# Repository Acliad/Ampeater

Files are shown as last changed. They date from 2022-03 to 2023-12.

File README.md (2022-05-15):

# Overview
This project is a 50 W electronic load. The table below outlines the basic specs for the load.

| Description | Spec |
|---|---|
| Supply Voltage | 12 V |
| Slew Rate | 10 A/µs |
| Maximum Current | 10 A |
| Maximum Power Dissipation | 50 W |
| Program Resolution (low range / high range) | 1 mA / 10 mA |
| Program Accuracy | 0.2% $\pm$ 0.2% FS |
| Maximum Overshoot | 1% |
| Measurement Readout Accuracy | 0.2% $\pm$ 0.2% FS |

The primary challenge with designing an electronic load is to making it stable over a wide range of load currents and input conditions. This challenges becomes worse when the design demands a fast rise time. The target slew rate for this load is 10 A/µs, which is quite fast. In comparison, the [Keysight EL34243A](https://www.keysight.com/zz/en/assets/3120-1430/data-sheets/EL30000-Series.pdf) has a slew rate of about 5 A/µs. 

This challenge is two-fold. The initial and obvious challenge is the control loop, which is discussed in detail in the [Theory Of Operation](#theory-of-operation) section. Simply, this requires proper compensation to maintain stability and rise time. The more nefarious issue is the issue of input impedance, largely due to the inductance of the wires connecting the load to the source being tested. This inductance is, in general, not known and can vary widely, in the range of 50 nH to 2 uH between short, heavy gauge wire and garden-variety banana cables. This inductance has a large affect on the control loop and can significantly change the rise time and stability of the load. 

Because the current level and slew rate are so large, the slew rate and overshoot specs are defined to be valid for input inductances in the range of 100 nH–roughly 10 cm of 12 AWG wire. This was the assumed input inductance during the design stage. 

# Design and Simulation
## The Control Loop
Figure 1 shows the main control circuit. The main compensation components have been highlighted. Q201 and gate resistors are used to switch the current range between 1 A and 10 A. For this analysis, assume either R211+R212 OR R214 is connected. R202 isolates the output of the opamp from the gate capacitance, which is required for stability. This compensator is known as a [*Type III compensator*](https://www.ti.com/seclit/ml/slup340/slup340.pdf). There are two compensators, each designed to sink up to 0.5/5.0 A. This is done to reduce power dissipation in each transistor.

<p align="center">
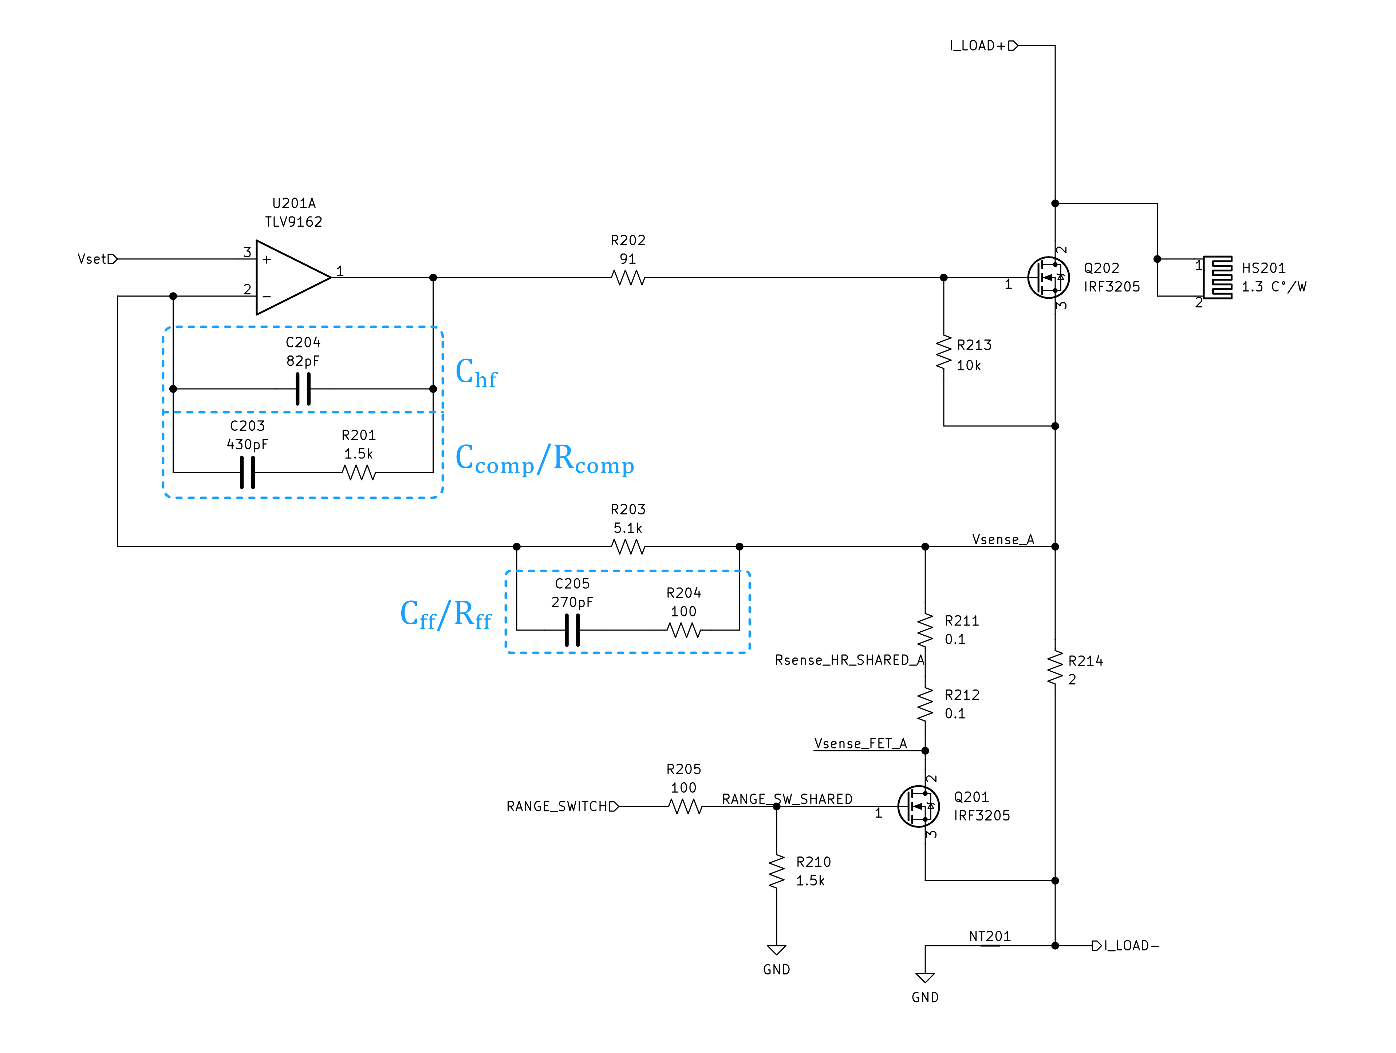
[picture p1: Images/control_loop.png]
 
<figcaption align = "center"><b>Figure 1: Control Loop Circuit</b></figcaption>
</p>

The poles and zeros of the compensator can be set by the compensation components outlined in Figure 1, with equations given in [Switch-mode power converter compensation made easy](https://www.ti.com/seclit/ml/slup340/slup340.pdf).

Figure 2 shows the SPICE simulation setup for the control loop, where the spice models for the TLV9162 were provided by TI and the spice models for the IRF3205 were provided by Infineon. R6 and C4 are used to compensate for the inductance L1. 

<p align="center">
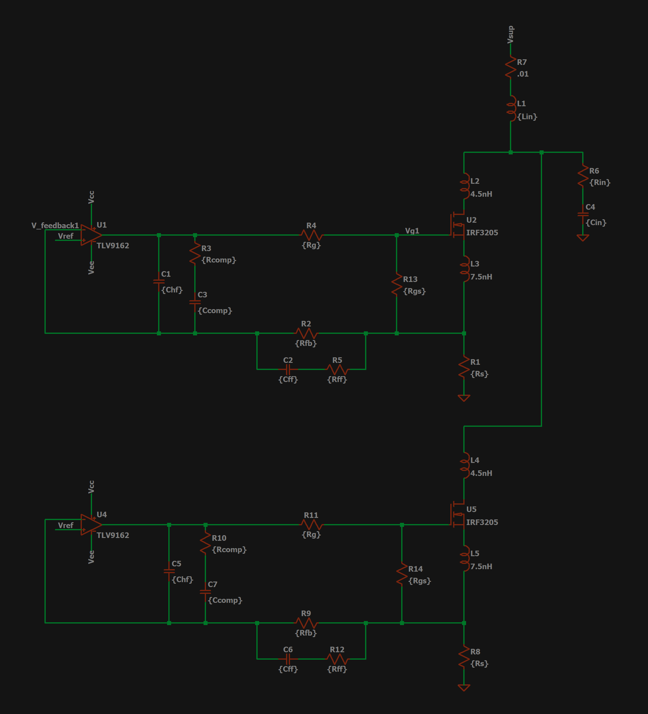
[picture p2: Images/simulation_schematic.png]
 
<figcaption align = "center"><b>Figure 2: Simulation Schematic</b></figcaption>
</p>

The values for the compensation components were tuned until the desired step response was obtained. Figure 3 below shows the simulated step response to 10 A for RS = 0.2, L1 = 100 nH. The compensation values are given in Figure 1. The overshoot spec is met and the 10% to 90% rise time was measured to be 1.03µs. 

<p align="center">
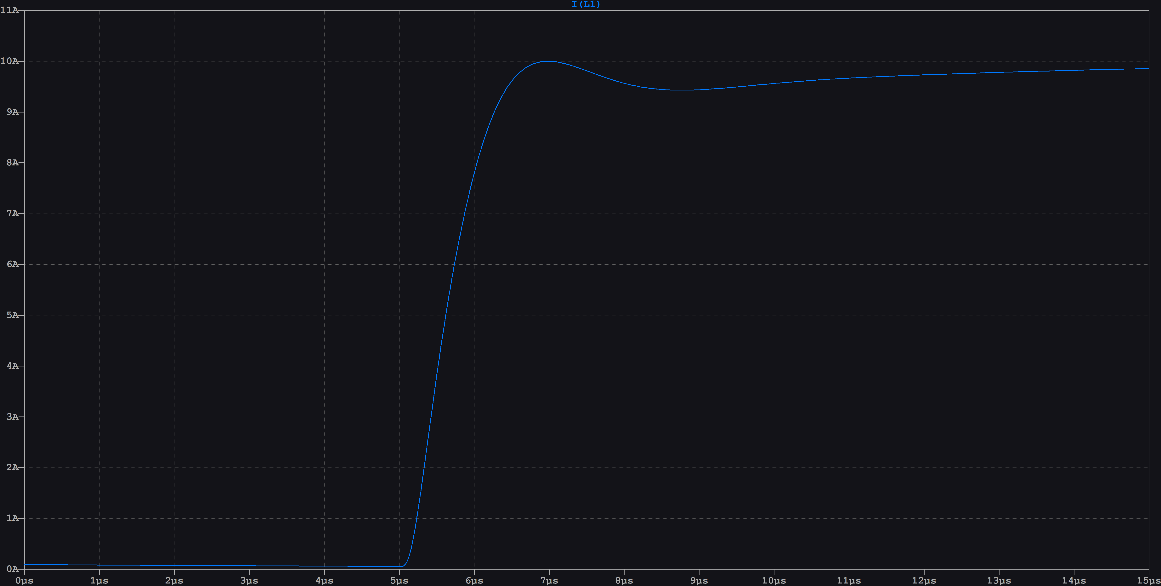
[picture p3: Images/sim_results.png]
 
<figcaption align = "center"><b>Figure 3: Simulated Step Response</b></figcaption>
</p>

## Controlling The Control Loop
An STM32L041 was used as the microcontroller for this board. It was chosen for its availability at the time of design (which was during the 2022 parts shortage). It features an on-board 12-bit ADC, which has enough resolution to meet the measurement specs, but the resolution can be further improved using hardware oversampling. 

A DAC is used to set the control voltage for the control loop. The chosen DAC is the ADI AD5452YRM, a fast settling time R2-R DAC. This DAC was chosen as the step response of the DAC needed to be at least as fast as the response of the overall control circuit. The chosen DAC should be more than sufficent for the task. 

Figure 4 shows the DAC arrangement. As noted in the image, the reference voltage is being fed into the current output pin of the DAC and the output voltage is being taken from the Vref pin. R2-R DACs generally allow this arrangement (unless the output is internally buffered), but typically require the reference voltage to be much less than than the supply voltage to overcome the required Vgs of the internal FETs. The ADI datasheet is not clear on how much larger Vcc should be, so the first attempt simply used a 3.3V supply. 

The output impedance of an R2-R DAC in this reverse arrangement is equal to the R value, which is 10k for the AD5452YRM. It is possible that the RC time constant could slow down the output transition, so the traces connecting the DAC to the opamp input should be kept short.
<p align="center">
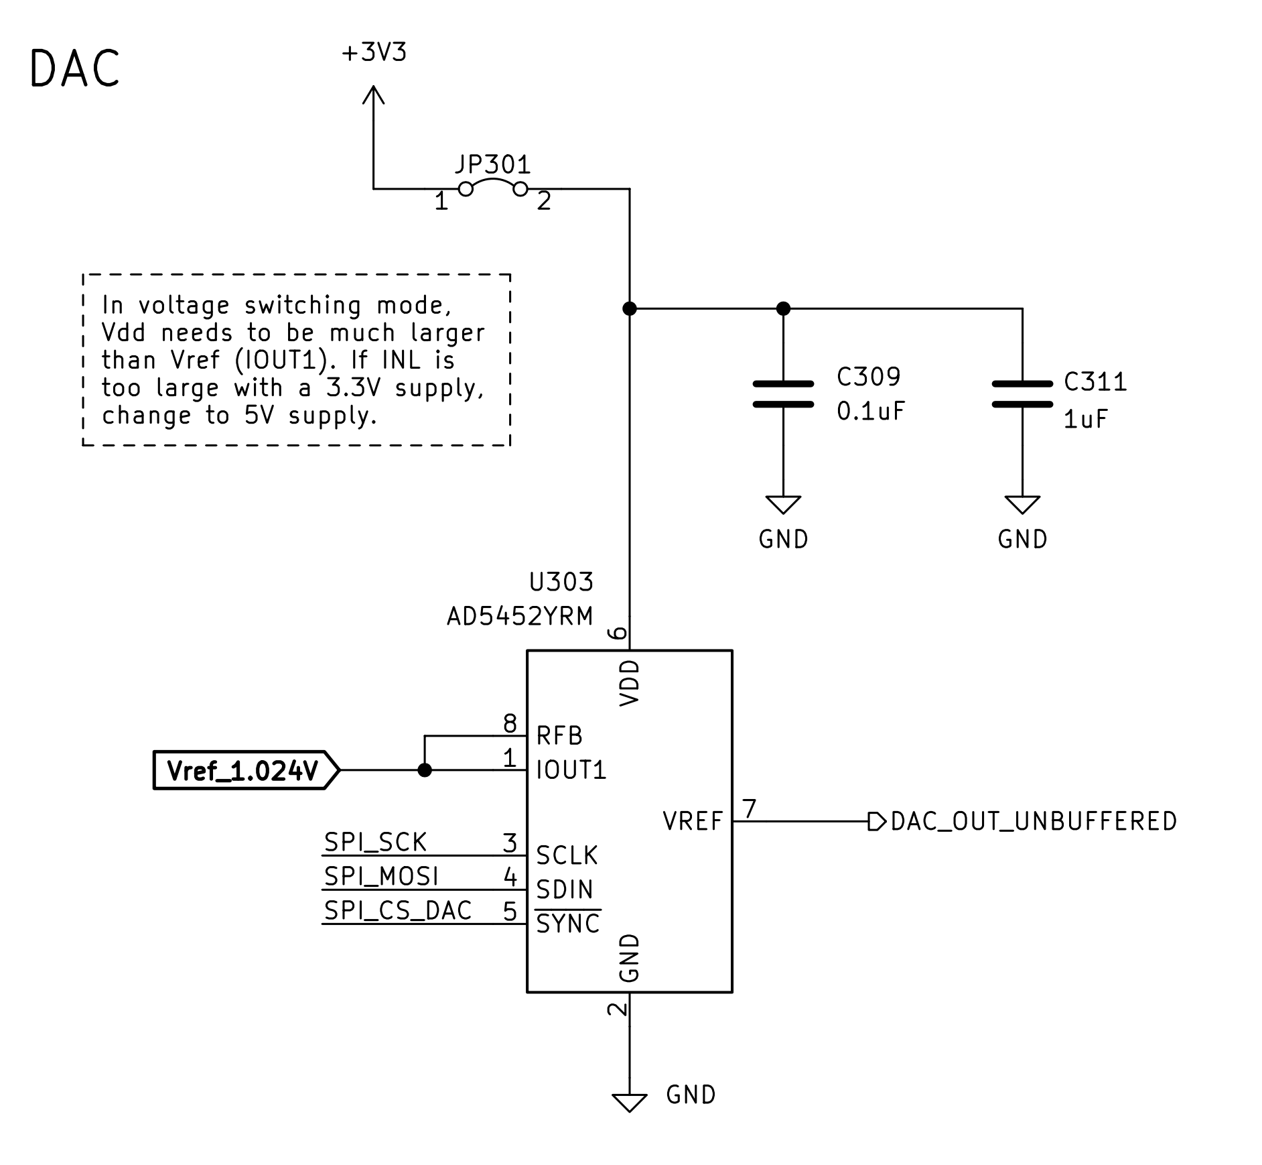
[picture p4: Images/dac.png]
 
<figcaption align = "center"><b>Figure 4: DAC Schematic Block</b></figcaption>
</p>

## Heatsinking
A large heatsink was chosen to be capable of dissipating at least 50 W with forced air cooling. The thermal calculations were done assuming smooth fin design, however, the chosen heatsink has serrated fins which should significantly improve the heatsinking ability. 

## Human Interfacing
A colored LCD, two pushbuttons, and a rotary encoder with a built-in push button is used to interface with the electronic load. The primary function of the buttons are:
- Output On/Off
- Slew Rate Setting
- Range Selection

The rotary encoder is used to set the load current.

# Results
The final board is shown in Figure 5. All basic DC functions worked including range switching, current measurement, and current sinking up to 10 A. It was found to be stable over the entire range of set current, with some small amount of ringing on the 10 A setting with 2X3ft (6ft ~ 2nH input inductance). 

<p align="center">
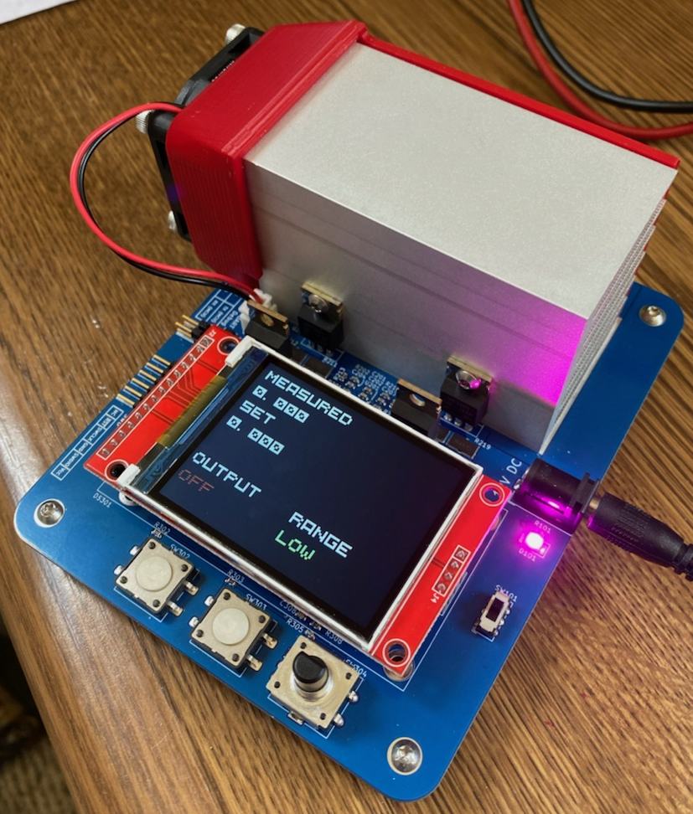
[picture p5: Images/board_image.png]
 
<figcaption align = "center"><b>Figure 5: Assembled Ampeater</b></figcaption>
</p>

The output was found to be overdamped when two 8 cm lengths of 12 AWG wire were used to connect to the load. The scope capture is shown in Figure 6. The capture is measured across Rsense of one of the control loops with a resistance of ~0.2 Ohms, so 1 V equals 10 A of load current. The capture shows a clearly overdamped response, which makes the load very stable but much slower than desired with a rise time of ~11 µs. To adjust this, the compensation components must be tuned and the measurement performed until the results are acceptable. This is still a TODO item. 

<p align="center">
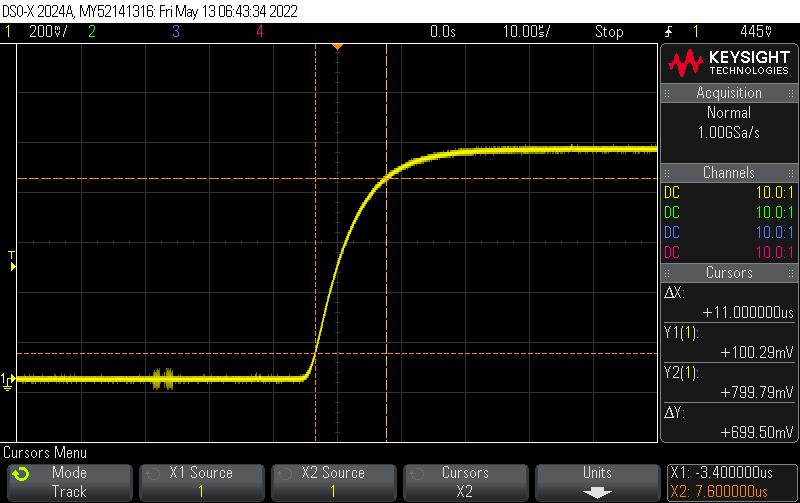
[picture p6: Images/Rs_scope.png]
 
<figcaption align = "center"><b>Figure 6: Scope capture measured across one controller's Rsense</b></figcaption>
</p>

Both the hardware and software are currently in prototype phase and much remains to be done, especially on the software side. However, early results are quite good and all specs appear to be met except the rise time. Tuning of component values will need to be done to ensure this spec is met.

# TODO
- ## Hardware
  - Add output buffer to range select switch
  - Increase reference voltage
  - (Probably) decrease low range current sense resistor
  - Make slightly longer for connectors
  - Add power switch labels
  - Add spots for R6 and C4 (simulation reference designators) compensation resistor/cap
  - Tune compensation values on prototype board to increase rise time. 
- ## Software
  - Investigate a continuos mode ADC sampling that doesn't require polling of every channel for a single channel read
  - Use a faster LCD Library utilizing DMA
  - Add proper return type and error throwing for completion 
  - Use the Vrefint to measure external VDDA for more accurate readings
  - Implement encoder velocity 
  - Implement slew rate limiting
  - Implement a calibration routine to calibrate to resistors 
- ## Documentation
  - Add more discussion on compensator in Theory Of Operation (not currently done do to the absurdity of trying to add equations to GitHub's Markdown)
  - Update images of board

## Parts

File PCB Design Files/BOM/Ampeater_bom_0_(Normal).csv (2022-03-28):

References | Value | Digi-Key PN | Quantity Per PCB | Footprint | Datasheet
C204, C207 | 82pF | 1276-CL10C820JB81PNDCT-ND | 2 | C_0603_1608Metric | ~
C205, C208 | 270pF | 1276-1256-1-ND | 2 | C_0603_1608Metric | ~
C203, C206 | 430pF | 490-1442-1-ND | 2 | C_0603_1608Metric | ~
C302, C305, C308 | 0.01uF | 1276-1009-1-ND | 3 | C_0603_1608Metric | ~
C202, C301, C304, C306, C309, C310 | 0.1uF | 1276-CL10B104KB8NNNLCT-ND | 6 | C_0603_1608Metric | ~
C201, C307, C311 | 1uF | 1276-1102-1-ND | 3 | C_0603_1608Metric | ~
C101, C102, C103, C303 | 10uF | 490-18214-1-ND | 4 | C_0603_1608Metric | ~
D301, D302 | 1N4007 | 1655-1N4007FLCT-ND | 2 | D_SOD-123F | ~
DS301 | 2.4" Color LCD |  | 1
HS201 | 1.3 C°/W |  | 1 |  | ~
J101 | 12V Input | CP-102AH-ND | 1 | BarrelJack_CUI_PJ-102AH_Horizontal | ~
J103 | I+_Banana | BKCT3151SP-4-ND | 1 | CalTest_CT3151 | ~
J105 | I-_Banana | BKCT3151SP-6-ND | 1 | CalTest_CT3151 | ~
J104 | I_TerminalBlock | 732-10955-ND | 1 | TerminalBlock_Philmore_TB132_1x02_P5.00mm_Horizontal | ~
J302 | SWD_Header | 2057-PH1RA-06-UA-ND | 1 | PinHeader_1x06_P2.54mm_Horizontal | ~
J301 | UART_Header | 2057-PH2RA-04-UA-ND | 1 | PinHeader_2x02_P2.54mm_Horizontal | ~
JP201 | 0603_Jumper |  | 1 | Jumper-2_0603_1608Metric_Trace12mil | ~
M201 | Fan | 455-2247-ND | 1 | JST_XH_B2B-XH-AM_1x02_P2.50mm_Vertical | ~
NT201 | NetTie_GND_I- |  | 1 | NetTie-2_SMD_Pad8.0mils | ~
NT202 | NetTie_GND_I- |  | 1 | NetTie-2_SMD_Pad8.0mils | ~
Q201, Q202, Q203, Q204 | IRF3205 | IRF3205PBF-ND | 4 | R_0603_1608Metric | ~
R211, R212, R219, R220 | 0.1 | 511-1692-1-ND | 4 | Rohm_GMR100_B6.40x3.20mm | ~
R214, R222 | 2 | 738-CSRT2512FT2R00-UPCT-ND | 2 | R_2512_6332Metric | ~
R202, R216 | 91 | 311-91.0HRCT-ND | 2 | R_0603_1608Metric | ~
R204, R205, R218, R310 | 100 | A106047CT-ND | 4 | R_0603_1608Metric | ~
R201, R210, R215, R301, R304 | 1.5k | A121524CT-ND | 5 | R_0603_1608Metric | ~
R203, R217 | 5.1k | CR0603-FX-5101ELFCT-ND | 2 | R_0603_1608Metric | ~
R305 | 6.2k | 13-RC0603FR-136K2LCT-ND | 1 | R_0603_1608Metric | ~
R206, R207, R208, R209, R213, R221, R306, R307, R308, R309 | 10k | A106048CT-ND | 10 | R_0603_1608Metric | ~
R303 | 13k | CR0603-FX-1302ELFCT-ND | 1 | R_0603_1608Metric | ~
R302 | 30k | CR0603-FX-3002ELFCT-ND | 1 | R_0603_1608Metric | ~
SW304 | Encoder/Range Select | PEC12R-4217F-S0024-ND | 1 | RotaryEncoder_Alps_EC12E-Switch_Vertical_H20mm | ~
SW302 | On/Off | 732-13655-1-ND | 1 | SW_PUSH-12mm_Wuerth-430476085716_HandSolder | ~
SW101 | Power Switch | EG1918-ND | 1 |  | ~
SW301 | RST | CKN12309-1-ND | 1 | SW_PUSH-12mm_Wuerth-430476085716_HandSolder | ~
SW303 | Slew Rate | 732-13655-1-ND | 1 | SW_PUSH-12mm_Wuerth-430476085716_HandSolder | ~
U303 | AD5452YRM | AD5452YRMZ-REEL7CT-ND | 1 | MSOP-8_3x3mm_P0.65mm | https://www.analog.com/media/en/technical-documentation/data-sheets/ad5450_5451_5452_5453.pdf
U101 | AZ1117-3.3 | AZ1117CD-3.3TRG1DICT-ND | 1 | TO-252-2 | https://www.diodes.com/assets/Datasheets/AZ1117.pdf
U302 | MCP1501 | MCP1501T-10E/CHYCT-ND | 1 | SOT-23-6 | http://ww1.microchip.com/downloads/en/DeviceDoc/20005474E.pdf
U301 | STM32L041F6Px | 497-16810-ND | 1 | TSSOP-20_4.4x6.5mm_P0.65mm | http://www.st.com/st-web-ui/static/active/en/resource/technical/document/datasheet/DM00152023.pdf
U201 | TLV9162 | TLV9162IDDFR | 1 | SOT-23-8 | ~
Component Groups: | 41
Component Count: | 82
Fitted Components: | 82
Number of PCBs: | 1
Total components: | 82
Schematic Version: | 0
Schematic Date: | 2022-03-14
PCB Variant: | normal
BoM Date: | Wednesday, March 16, 2022 at 10:53:04 AM
Schematic Source: | Ampeater.kicad_sch
KiCad Version: | Eeschema (6.0.2-0)

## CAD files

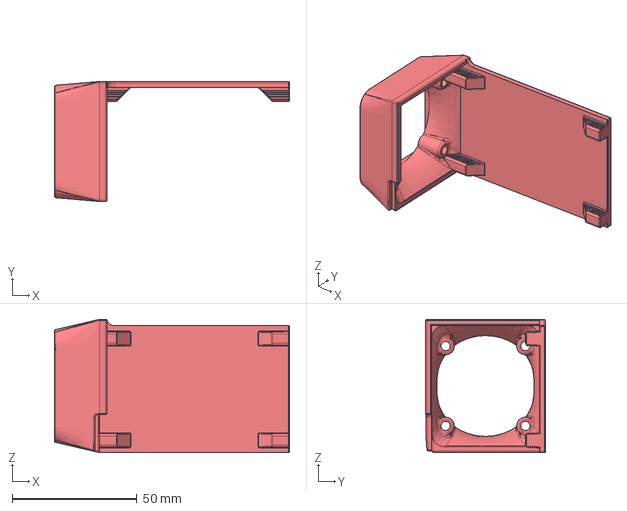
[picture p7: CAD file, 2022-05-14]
Mechanical/Step/Fan Shroud.step
94.2 x 48.1 x 53.4 mm

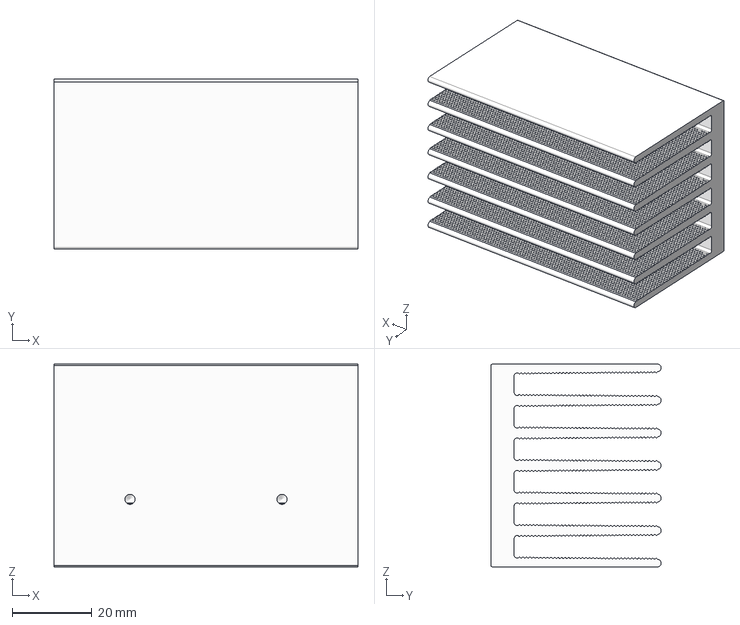
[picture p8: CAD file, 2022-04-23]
Mechanical/Step/2x3inch Serated Heat Sink.step
76.2 x 42.7 x 50.8 mm

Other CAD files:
Mechanical/Printable/Fan Shroud.3mf

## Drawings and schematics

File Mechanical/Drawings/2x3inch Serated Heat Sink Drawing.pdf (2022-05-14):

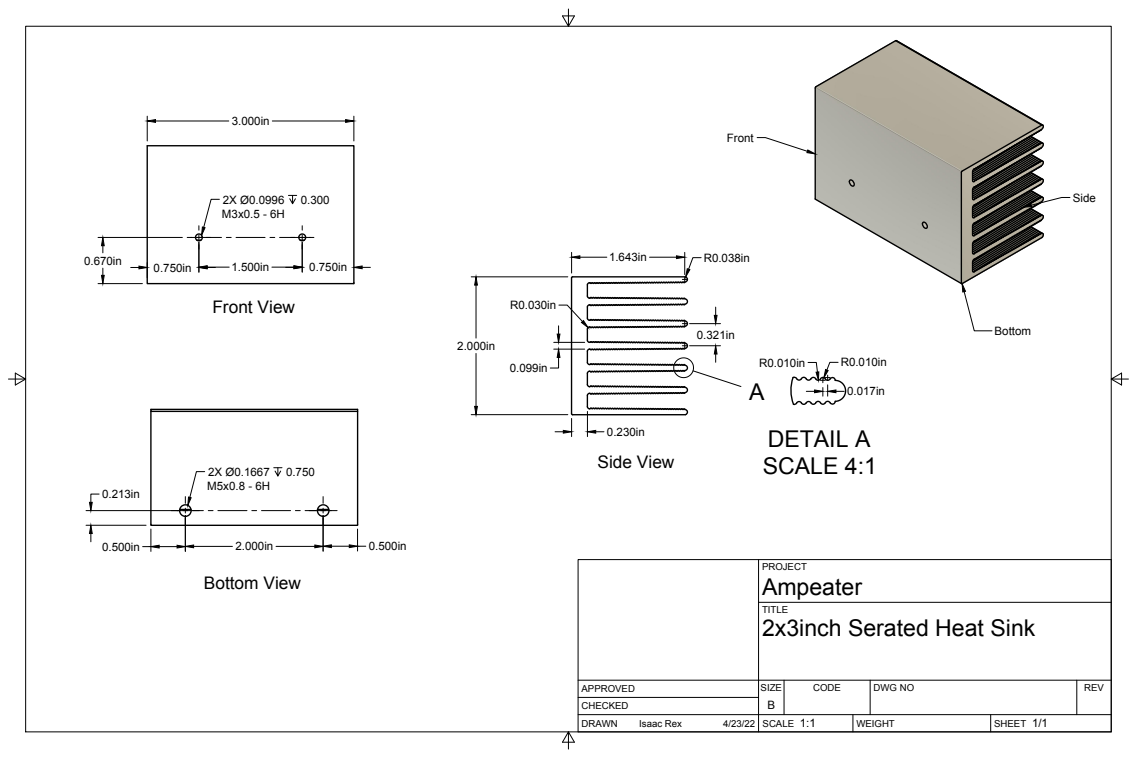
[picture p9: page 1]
SIZE; CODE; DWG NO; REV; Isaac Rex; Front View; Bottom View; DETAIL A SCALE 4:1; Side View

PROJECT
Ampeater
2x3inch Serated Heat Sink

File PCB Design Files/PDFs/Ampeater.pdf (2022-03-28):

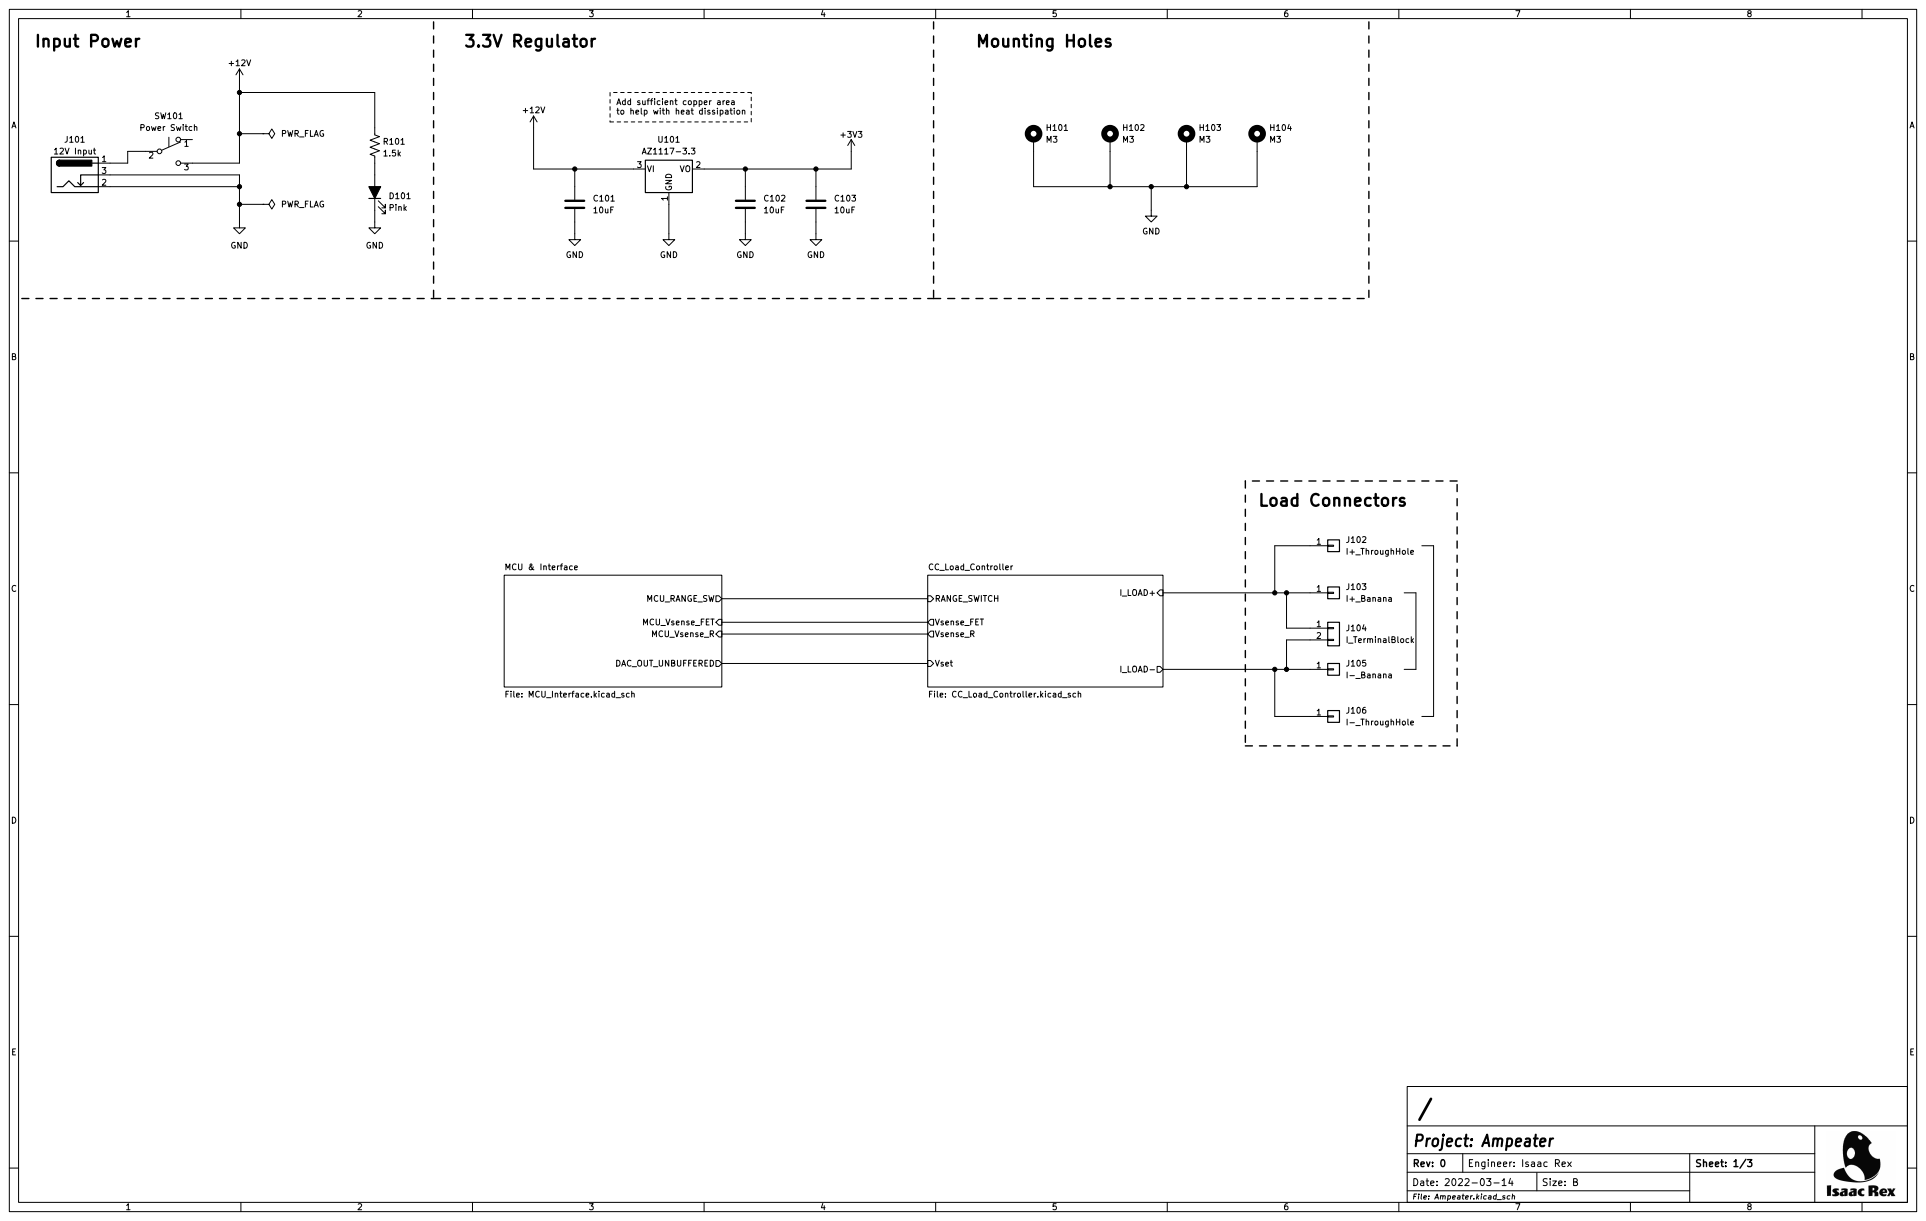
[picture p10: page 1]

Add sufficient copper area
to help with heat dissipation

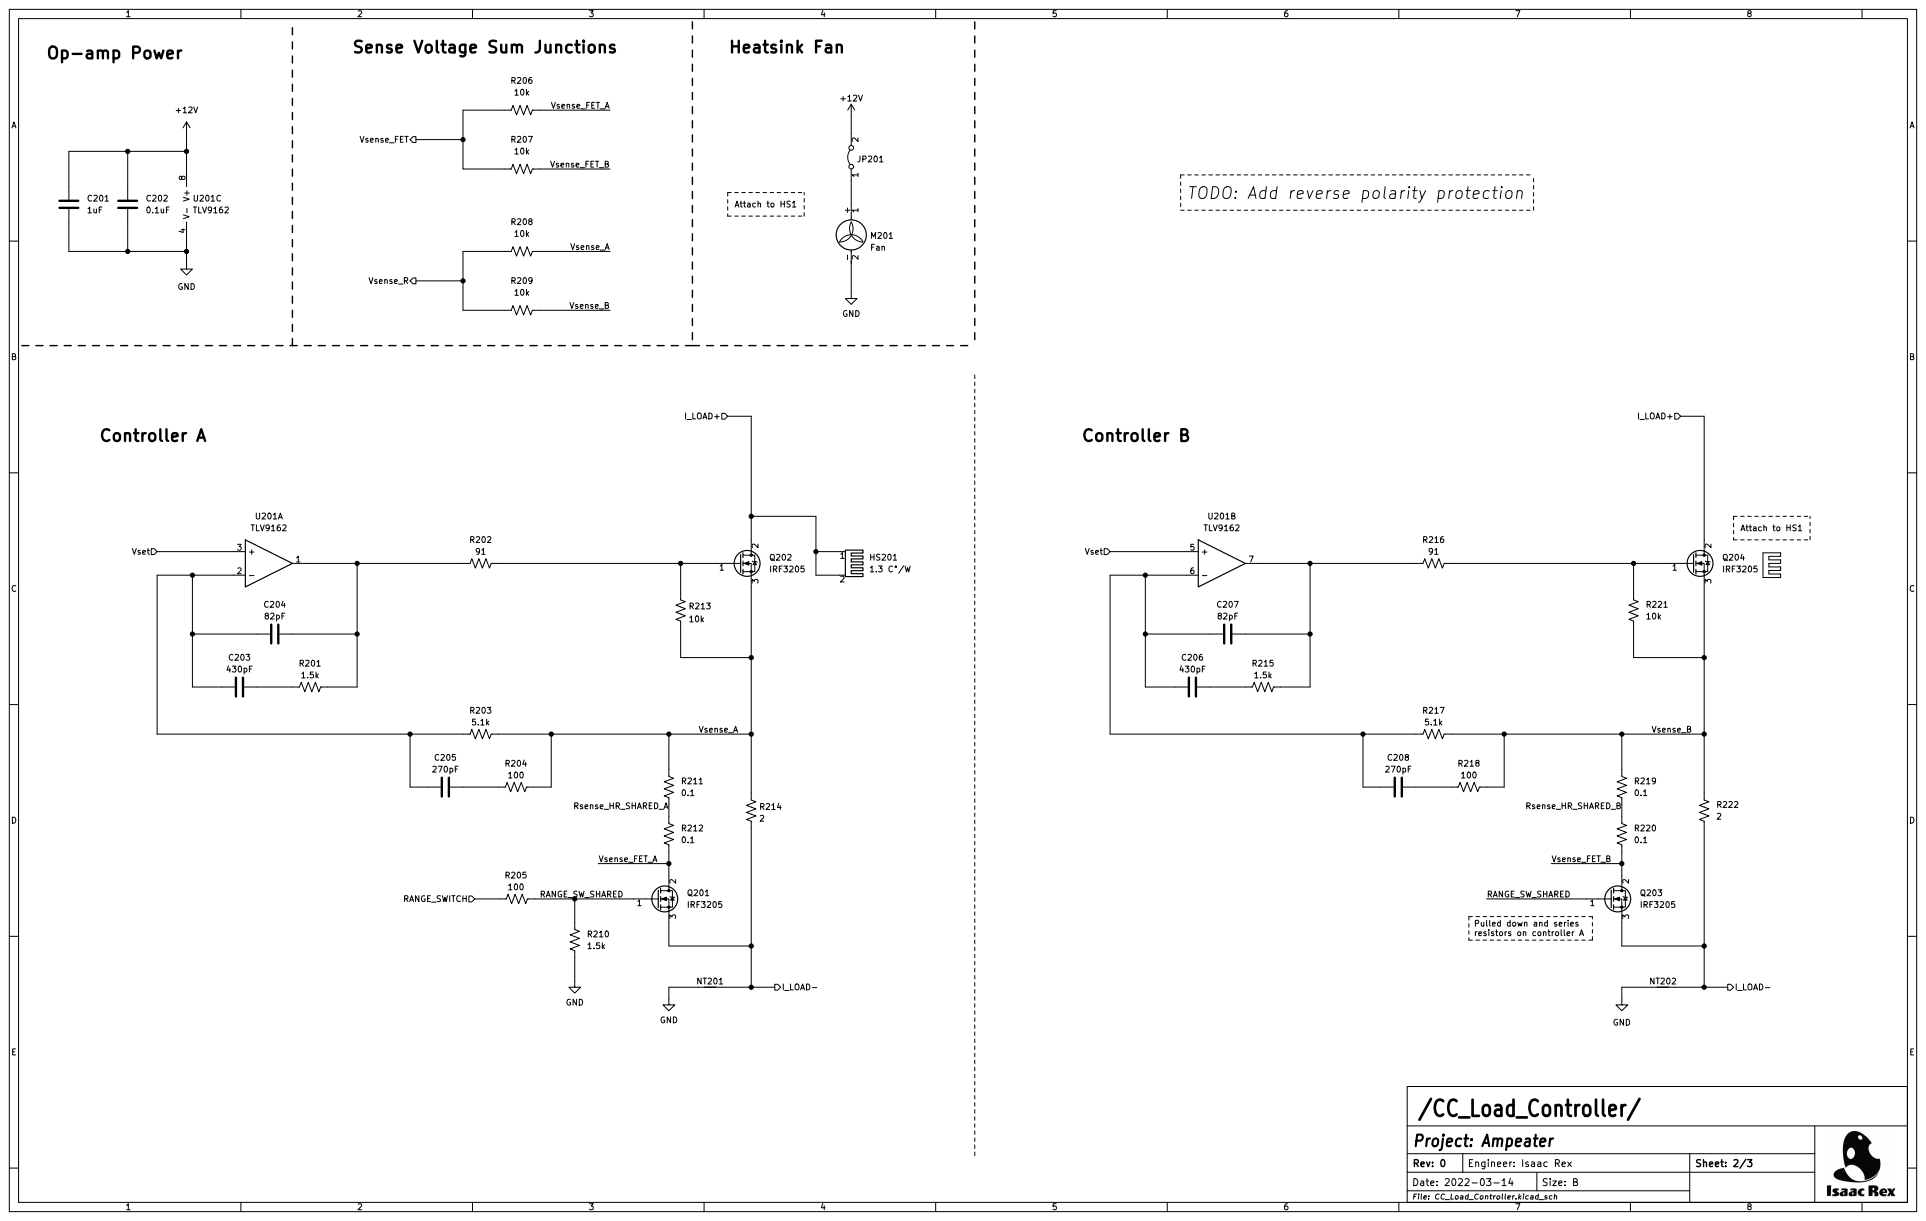
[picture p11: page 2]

Attach to HS1 Heatsink Fan

TODO: Add reverse polarity protection

Engineer: Isaac Rex GND

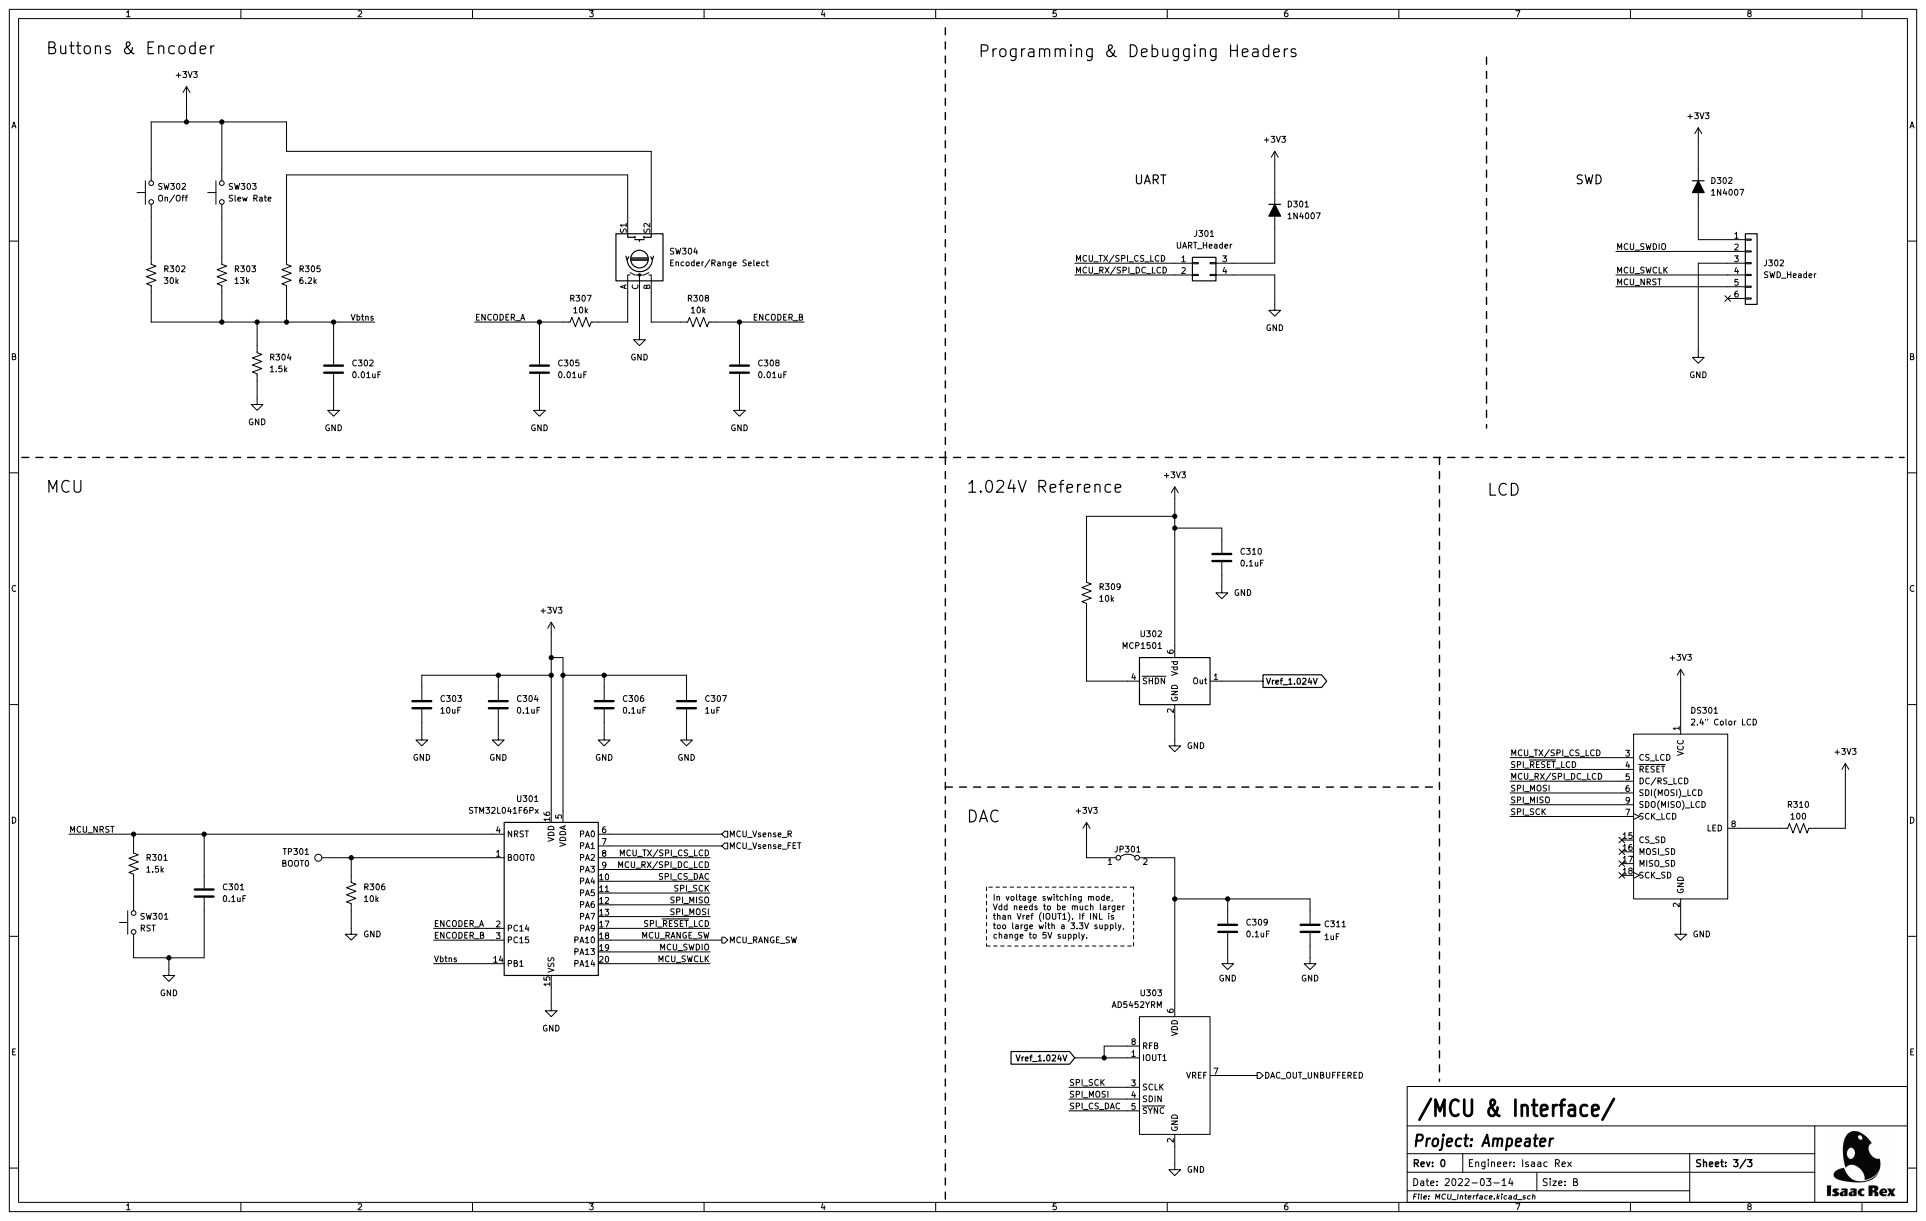
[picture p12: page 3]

In voltage switching mode,
Vdd needs to be much larger
than Vref (IOUT1). If INL is
too large with a 3.3V supply,
change to 5V supply.

2 SCLK 3 SDIN 4 ~{SYNC} 5 VDD

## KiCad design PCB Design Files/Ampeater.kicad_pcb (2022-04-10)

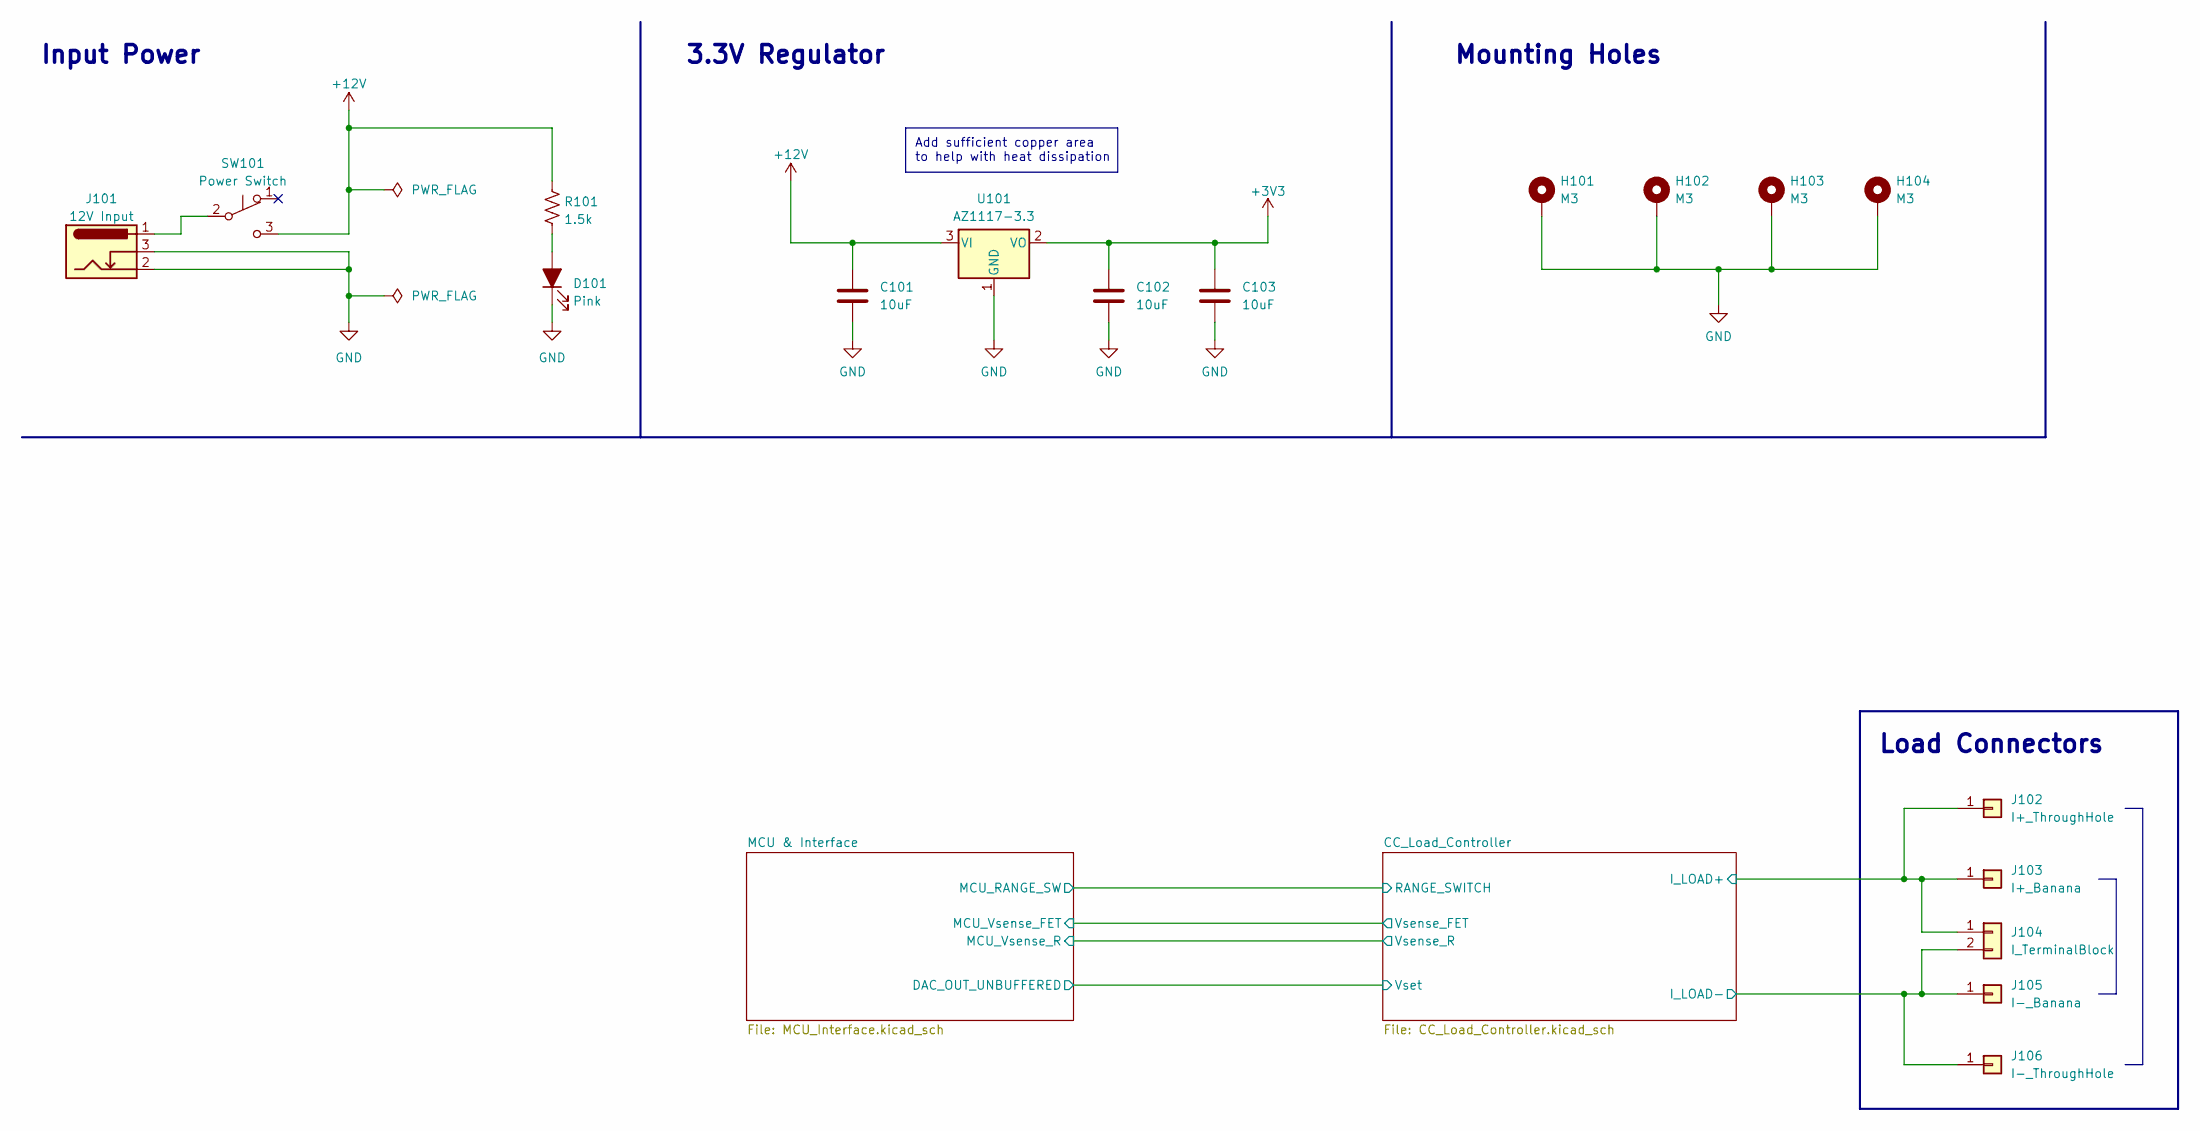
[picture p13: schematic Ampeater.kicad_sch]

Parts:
C101, C102, C103: 10uF; C_0603_1608Metric; Digi-Key PN 490-18214-1-ND
D101: Pink; LED_Kingbright_AA3528V_3.5x2.8mm_handsolder
H101, H102, H103, H104: M3; MountingHole_3.2mm_M3_Pad
J101: 12V Input; BarrelJack_CUI_PJ-102AH_Horizontal; Digi-Key PN CP-102AH-ND
J102: I+_ThroughHole; TestPoint_THTPad_D4.0mm_Drill2.0mm
J103: I+_Banana; CalTest_CT3151; Digi-Key PN BKCT3151SP-4-ND
J104: I_TerminalBlock; TerminalBlock_Philmore_TB132_1x02_P5.00mm_Horizontal; Digi-Key PN 732-10955-ND
J105: I-_Banana; CalTest_CT3151; Digi-Key PN BKCT3151SP-6-ND
J106: I-_ThroughHole; TestPoint_THTPad_D4.0mm_Drill2.0mm
R101: 1.5k; R_0603_1608Metric; Digi-Key PN A121524CT-ND
SW101: Power Switch; SW_E-Switch_EG1271_SPDT; Digi-Key PN EG1918-ND
U101: AZ1117-3.3; TO-252-2; Digi-Key PN AZ1117CD-3.3TRG1DICT-ND

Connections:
+3V3: C102.1, C103.1, U101.2 (VO); also elsewhere on the board
+12V: C101.1, R101.1, SW101.3 (C), U101.3 (VI); also elsewhere on the board
/CC_Load_Controller/I_LOAD+: J102.1, J103.1, J104.1; also elsewhere on the board
/CC_Load_Controller/I_LOAD-: J104.2, J105.1, J106.1; also elsewhere on the board
GND: C101.2, C102.2, C103.2, D101.1 (K), H101.1, H102.1, H103.1, H104.1, J101.2, J101.3, U101.1 (GND); also elsewhere on the board
unnamed: D101.2 (A), R101.2
unnamed: J101.1, SW101.2 (B)

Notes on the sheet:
3.3V Regulator
Mounting Holes
Load Connectors
Add sufficient copper area to help with heat dissipation
Input Power

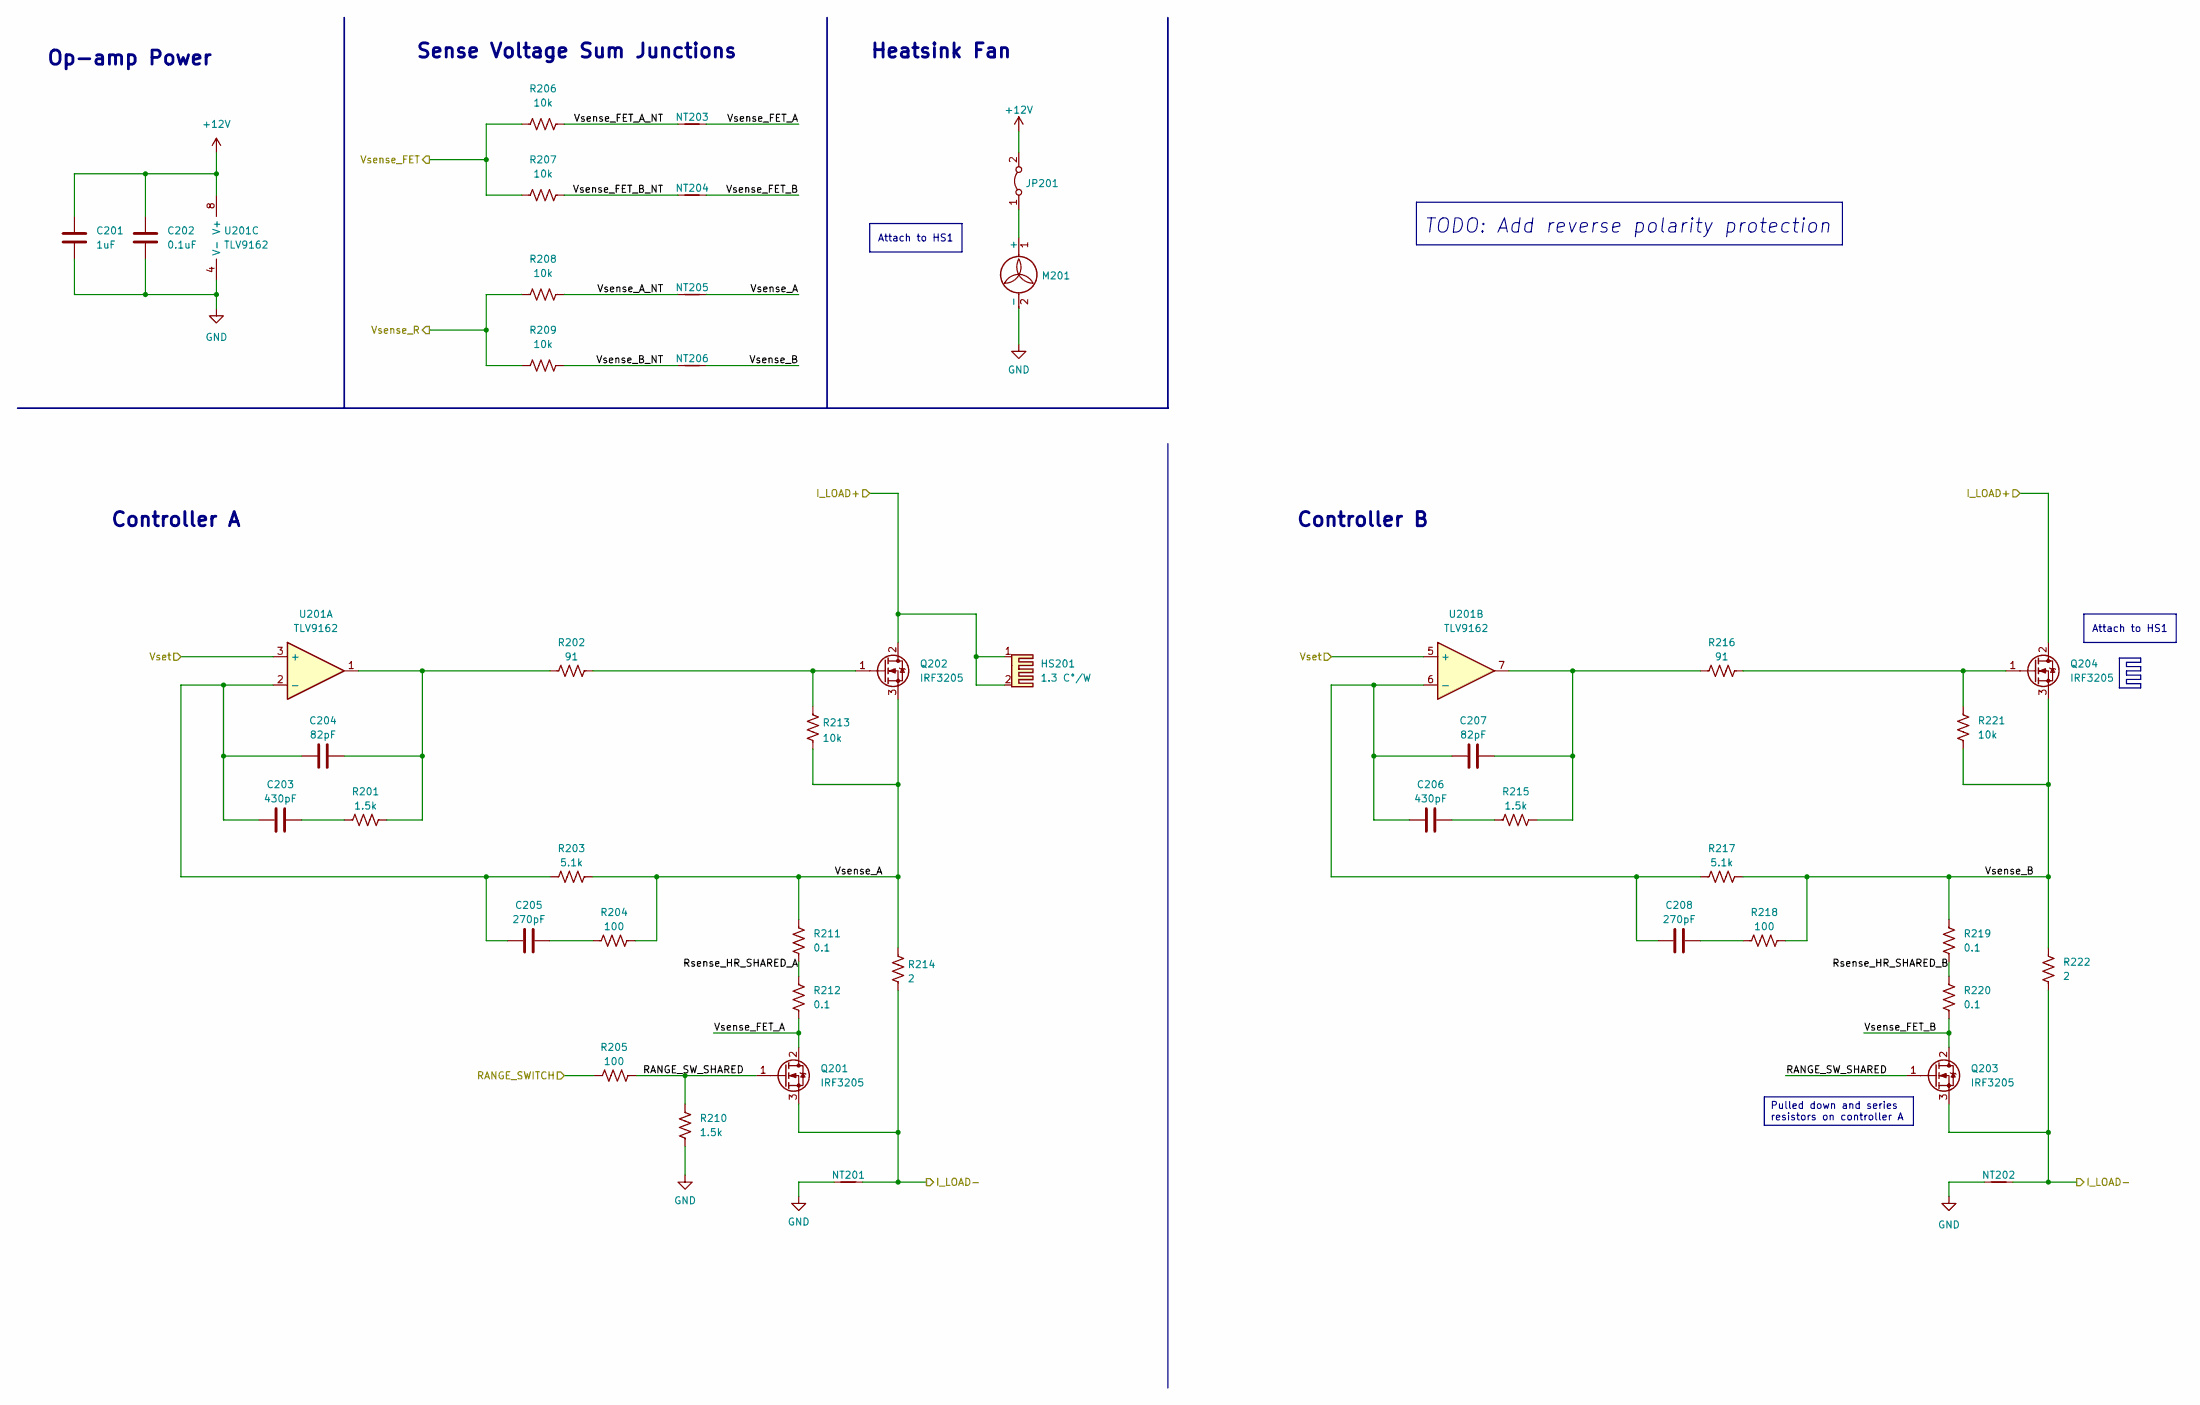
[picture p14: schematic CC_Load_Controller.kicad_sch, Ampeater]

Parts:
C201: 1uF; C_0603_1608Metric; Digi-Key PN 1276-1102-1-ND
C202: 0.1uF; C_0603_1608Metric; Digi-Key PN 1276-CL10B104KB8NNNLCT-ND
C203, C206: 430pF; C_0603_1608Metric; Digi-Key PN 490-1442-1-ND
C204, C207: 82pF; C_0603_1608Metric; Digi-Key PN 1276-CL10C820JB81PNDCT-ND
C205, C208: 270pF; C_0603_1608Metric; Digi-Key PN 1276-1256-1-ND
HS201: 1.3 C°/W; Heatsink_HeatsinkUSA_3.00x1.65in_2xDrill5.25mm_TO-220-Mount
JP201: 0603_Jumper; Jumper-2_0603_1608Metric_Trace12mil
M201: Digi-Key PN 455-2247-ND
NT201, NT202: NetTie_GND_I-; NetTie-2_SMD_Pad8.0mils
NT203, NT204, NT205, NT206: (no value)
Q201, Q202, Q203, Q204: IRF3205; TO-220-3_Vertical; Digi-Key PN IRF3205PBF-ND
R201, R210, R215: 1.5k; R_0603_1608Metric; Digi-Key PN A121524CT-ND
R202, R216: 91; R_0603_1608Metric; Digi-Key PN 311-91.0HRCT-ND
R203, R217: 5.1k; R_0603_1608Metric; Digi-Key PN CR0603-FX-5101ELFCT-ND
R204, R205, R218: 100; R_0603_1608Metric; Digi-Key PN A106047CT-ND
R206, R207, R208, R209, R213, R221: 10k; R_0603_1608Metric; Digi-Key PN A106048CT-ND
R211, R212, R219, R220: 0.1; Rohm_GMR100_B6.40x3.20mm; Digi-Key PN 511-1692-1-ND
R214, R222: 2; R_2512_6332Metric; Digi-Key PN 738-CSRT2512FT2R00-UPCT-ND
U201: TLV9162; SOT-23-8; Digi-Key PN TLV9162IDDFR

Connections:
+12V: C201.1, C202.1, JP201.2 (B), U201.8 (V+); also elsewhere on the board
/CC_Load_Controller/I_LOAD+: HS201.1, HS201.2, Q202.2 (D), Q204.2 (D); also elsewhere on the board
/CC_Load_Controller/I_LOAD-: NT201.2, NT202.2, Q201.3 (S), Q203.3 (S), R214.1, R222.1; also elsewhere on the board
/CC_Load_Controller/RANGE_SW_SHARED: Q201.1 (G), Q203.1 (G), R205.2, R210.2
/CC_Load_Controller/Rsense_HR_SHARED_A: R211.1, R212.2
/CC_Load_Controller/Rsense_HR_SHARED_B: R219.1, R220.2
/CC_Load_Controller/Vsense_A: NT205.2, Q202.3 (S), R203.2, R204.2, R211.2, R213.1, R214.2
/CC_Load_Controller/Vsense_A_NT: NT205.1, R208.1
/CC_Load_Controller/Vsense_B: NT206.2, Q204.3 (S), R217.2, R218.2, R219.2, R221.1, R222.2
/CC_Load_Controller/Vsense_B_NT: NT206.1, R209.1
/CC_Load_Controller/Vsense_FET: R206.2, R207.2; also elsewhere on the board
/CC_Load_Controller/Vsense_FET_A: NT203.2, Q201.2 (D), R212.1
/CC_Load_Controller/Vsense_FET_A_NT: NT203.1, R206.1
/CC_Load_Controller/Vsense_FET_B: NT204.2, Q203.2 (D), R220.1
/CC_Load_Controller/Vsense_FET_B_NT: NT204.1, R207.1
/CC_Load_Controller/Vsense_R: R208.2, R209.2; also elsewhere on the board
/CC_Load_Controller/Vset: U201.3 (+), U201.5 (+); also elsewhere on the board
/MCU & Interface/MCU_RANGE_SW: R205.1; also elsewhere on the board
GND: C201.2, C202.2, M201.2 (-), NT201.1, NT202.1, R210.1, U201.4 (V-); also elsewhere on the board
unnamed: C203.1, C204.1, C205.1, R203.1, U201.2 (-)
unnamed: C203.2, R201.1
unnamed: C204.2, R201.2, R202.1, U201.1
unnamed: C205.2, R204.1
unnamed: C206.1, C207.1, C208.1, R217.1, U201.6 (-)
unnamed: C206.2, R215.1
unnamed: C207.2, R215.2, R216.1, U201.7
unnamed: C208.2, R218.1
unnamed: JP201.1 (A), M201.1 (+)
unnamed: Q202.1 (G), R202.2, R213.2
unnamed: Q204.1 (G), R216.2, R221.2

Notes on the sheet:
Heatsink Fan
Pulled down and series resistors on controller A
Attach to HS1
Op-amp Power
Controller A
TODO: Add reverse polarity protection
Sense Voltage Sum Junctions
Controller B

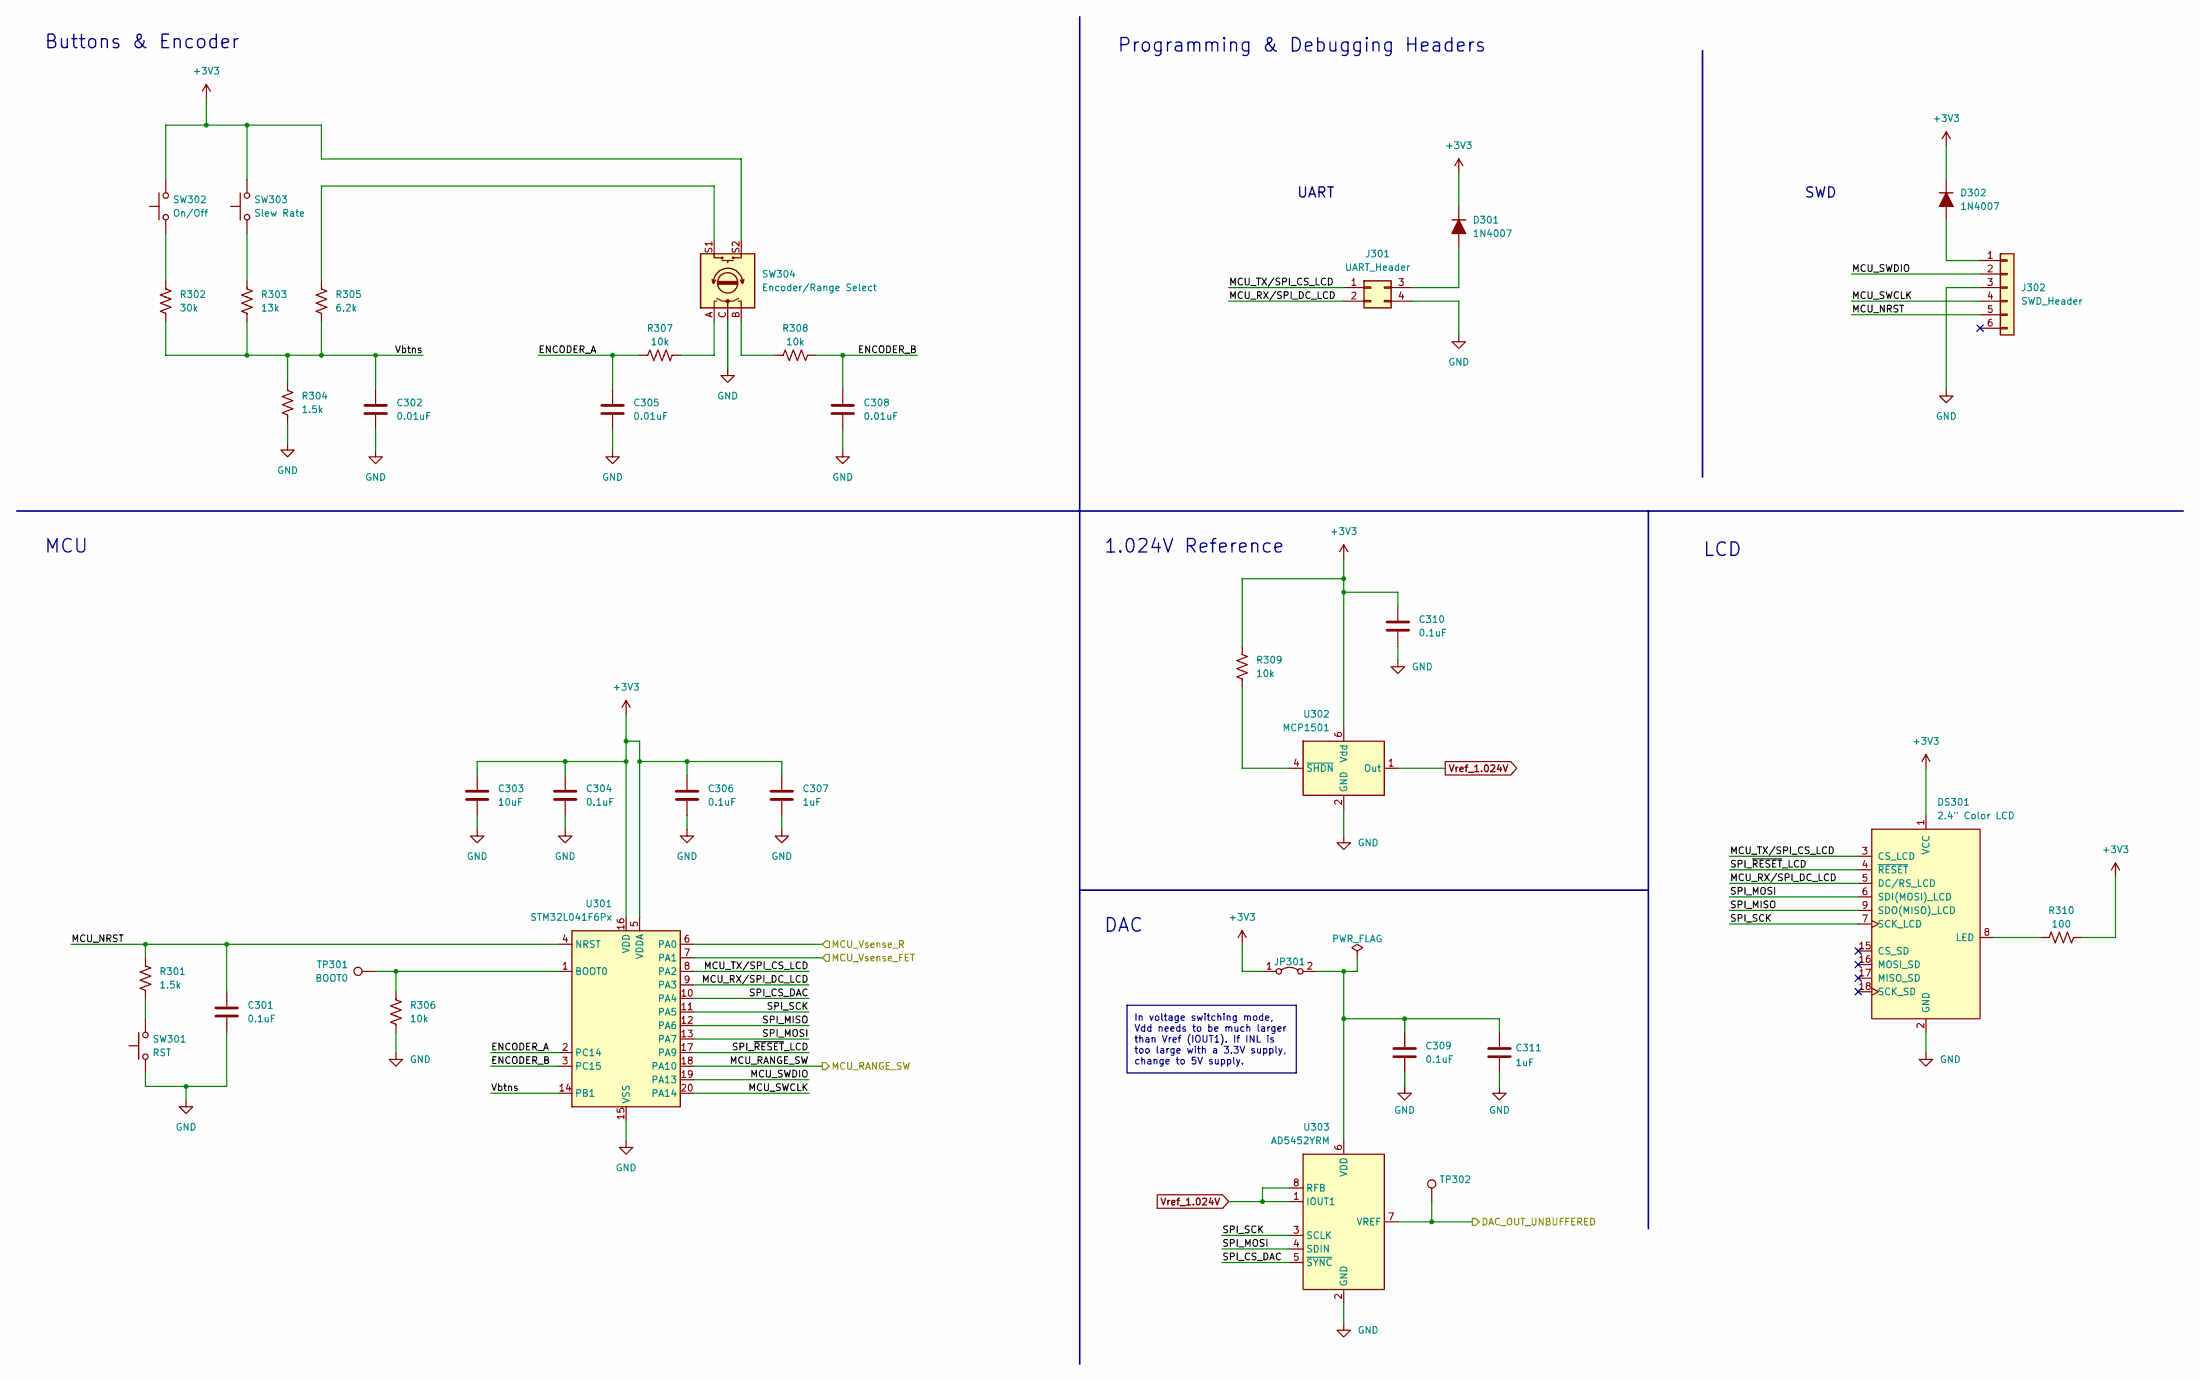
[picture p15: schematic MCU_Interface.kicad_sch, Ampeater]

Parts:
C301, C304, C306, C309, C310: 0.1uF; C_0603_1608Metric; Digi-Key PN 1276-CL10B104KB8NNNLCT-ND
C302, C305, C308: 0.01uF; C_0603_1608Metric; Digi-Key PN 1276-1009-1-ND
C303: 10uF; C_0603_1608Metric; Digi-Key PN 490-18214-1-ND
C307, C311: 1uF; C_0603_1608Metric; Digi-Key PN 1276-1102-1-ND
D301, D302: 1N4007; D_SOD-123F; Digi-Key PN 1655-1N4007FLCT-ND
DS301: 2.4" Color LCD; LCD-Generic-2.4in_77.18x42.72mm_ReducedCourtyard
J301: UART_Header; PinHeader_2x02_P2.54mm_Horizontal; Digi-Key PN 2057-PH2RA-04-UA-ND
J302: SWD_Header; PinHeader_1x06_P2.54mm_Horizontal; Digi-Key PN 2057-PH1RA-06-UA-ND
JP301: DAC_Jumper; SolderJumper-2_P1.3mm_Bridged_RoundedPad1.0x1.5mm
R301, R304: 1.5k; R_0603_1608Metric; Digi-Key PN A121524CT-ND
R302: 30k; R_0603_1608Metric; Digi-Key PN CR0603-FX-3002ELFCT-ND
R303: 13k; R_0603_1608Metric; Digi-Key PN CR0603-FX-1302ELFCT-ND
R305: 6.2k; R_0603_1608Metric; Digi-Key PN 13-RC0603FR-136K2LCT-ND
R306, R307, R308, R309: 10k; R_0603_1608Metric; Digi-Key PN A106048CT-ND
R310: 100; R_0603_1608Metric; Digi-Key PN A106047CT-ND
SW301: RST; SW-PUSH-6x3.5mm_CK-PTS636SL43x_HandSolder; Digi-Key PN CKN12309-1-ND
SW302: On/Off; SW_PUSH-12mm_Wuerth-430476085716_HandSolder; Digi-Key PN 732-13655-1-ND
SW303: Slew Rate; SW_PUSH-12mm_Wuerth-430476085716_HandSolder; Digi-Key PN 732-13655-1-ND
SW304: Encoder/Range Select; RotaryEncoder_Alps_EC12E-Switch_Vertical_H20mm; Digi-Key PN PEC12R-4217F-S0024-ND
TP301: BOOT0; TestPoint_THTPad_D2.5mm_Drill1.2mm
TP302: (no value)
U301: STM32L041F6Px; TSSOP-20_4.4x6.5mm_P0.65mm; Digi-Key PN 497-16810-ND
U302: MCP1501; SOT-23-6; Digi-Key PN MCP1501T-10E/CHYCT-ND
U303: AD5452YRM; MSOP-8_3x3mm_P0.65mm; Digi-Key PN AD5452YRMZ-REEL7CT-ND

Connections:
+3V3: C303.1, C304.1, C306.1, C307.1, C310.1, D301.1 (K), D302.1 (K), DS301.1 (VCC), JP301.1 (A), R309.1, R310.2, SW302.2, SW303.2, SW304.S2, U301.5 (VDDA), U301.16 (VDD), U302.6 (Vdd); also elsewhere on the board
/CC_Load_Controller/Vsense_FET: U301.7 (PA1); also elsewhere on the board
/CC_Load_Controller/Vsense_R: U301.6 (PA0); also elsewhere on the board
/CC_Load_Controller/Vset: TP302.1, U303.7 (VREF); also elsewhere on the board
/MCU & Interface/ENCODER_A: C305.1, R307.1, U301.2 (PC14)
/MCU & Interface/ENCODER_B: C308.1, R308.2, U301.3 (PC15)
/MCU & Interface/MCU_NRST: C301.1, J302.5, R301.1, U301.4 (NRST)
/MCU & Interface/MCU_RANGE_SW: U301.18 (PA10); also elsewhere on the board
/MCU & Interface/MCU_RX/SPI_DC_LCD: DS301.5 (DC/RS_LCD), J301.2, U301.9 (PA3)
/MCU & Interface/MCU_SWCLK: J302.4, U301.20 (PA14)
/MCU & Interface/MCU_SWDIO: J302.2, U301.19 (PA13)
/MCU & Interface/MCU_TX/SPI_CS_LCD: DS301.3 (CS_LCD), J301.1, U301.8 (PA2)
/MCU & Interface/SPI_CS_DAC: U301.10 (PA4), U303.5 (~SYNC)
/MCU & Interface/SPI_MISO: DS301.9 (SDO(MISO)_LCD), U301.12 (PA6)
/MCU & Interface/SPI_MOSI: DS301.6 (SDI(MOSI)_LCD), U301.13 (PA7), U303.4 (SDIN)
/MCU & Interface/SPI_SCK: DS301.7 (SCK_LCD), U301.11 (PA5), U303.3 (SCLK)
/MCU & Interface/SPI_~RESET_LCD: DS301.4 (~RESET), U301.17 (PA9)
/MCU & Interface/Vbtns: C302.1, R302.2, R303.2, R304.1, R305.2, U301.14 (PB1)
GND: C301.2, C302.2, C303.2, C304.2, C305.2, C306.2, C307.2, C308.2, C309.2, C310.2, C311.2, DS301.2 (GND), J301.4, J302.3, R304.2, R306.2, SW301.1, SW304.C, U301.15 (VSS), U302.2 (GND), U302.3 (GND), U302.5 (GND), U303.2 (GND); also elsewhere on the board
unnamed: C309.1, C311.1, JP301.2 (B), U303.6 (VDD)
unnamed: D301.2 (A), J301.3
unnamed: D302.2 (A), J302.1
unnamed: DS301.8 (LED), R310.1
unnamed: R301.2, SW301.2
unnamed: R302.1, SW302.1
unnamed: R303.1, SW303.1
unnamed: R305.1, SW304.S1
unnamed: R306.1, TP301.1, U301.1 (BOOT0)
unnamed: R307.2, SW304.A
unnamed: R308.1, SW304.B
unnamed: R309.2, U302.4 (~SHDN)
Vref_1.024V: U302.1 (Out), U303.1 (IOUT1), U303.8 (RFB)

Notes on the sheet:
Buttons & Encoder
SWD
UART
LCD
1.024V Reference
Programming & Debugging Headers
MCU
In voltage switching mode, Vdd needs to be much larger than Vref (IOUT1). If INL is too large with a 3.3V supply, change to 5V supply.
DAC

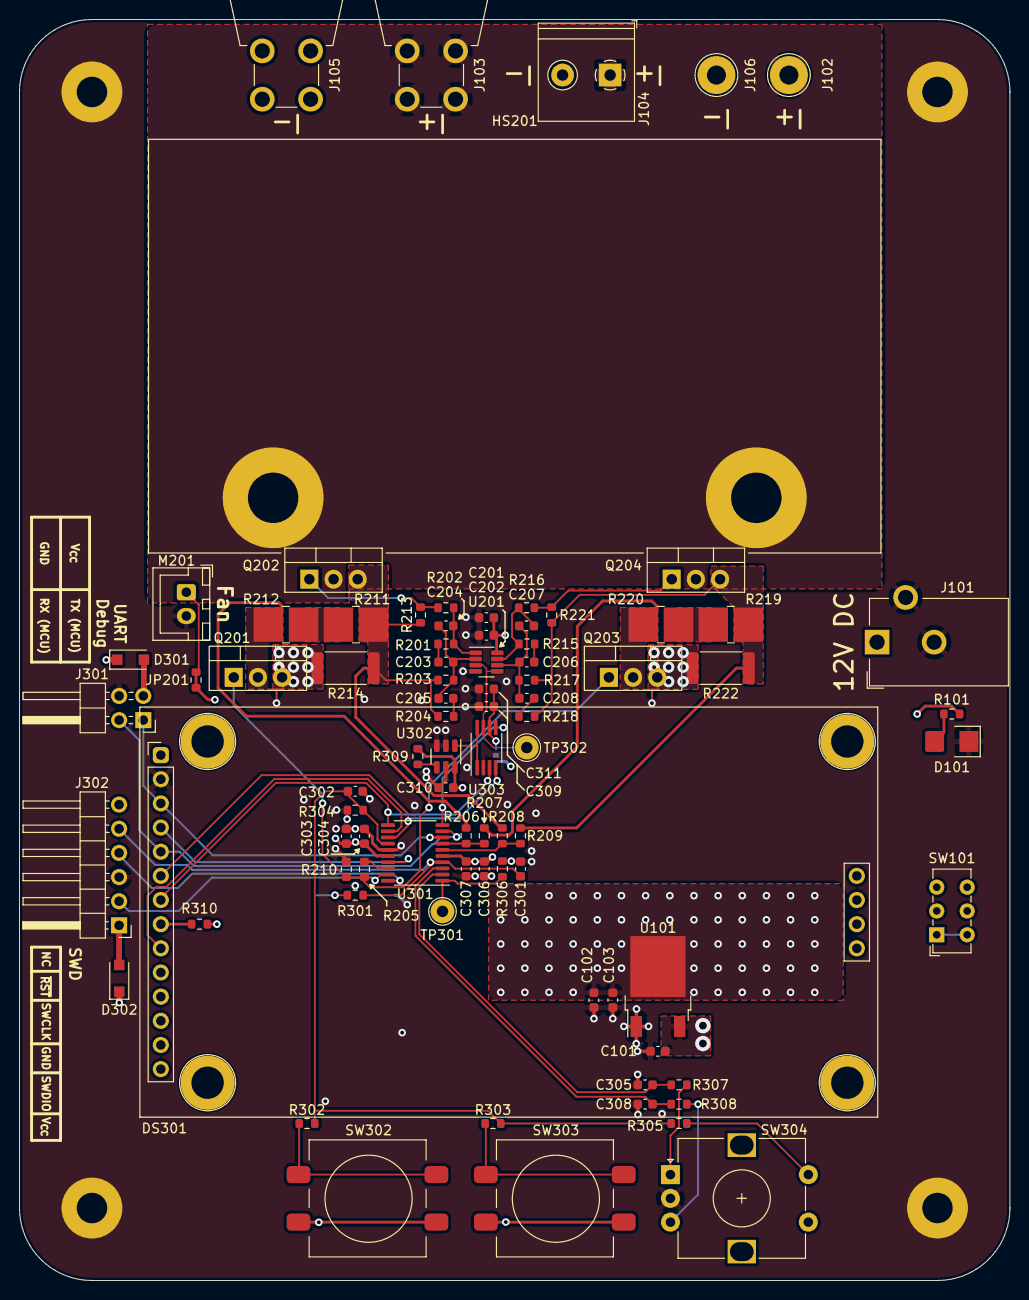
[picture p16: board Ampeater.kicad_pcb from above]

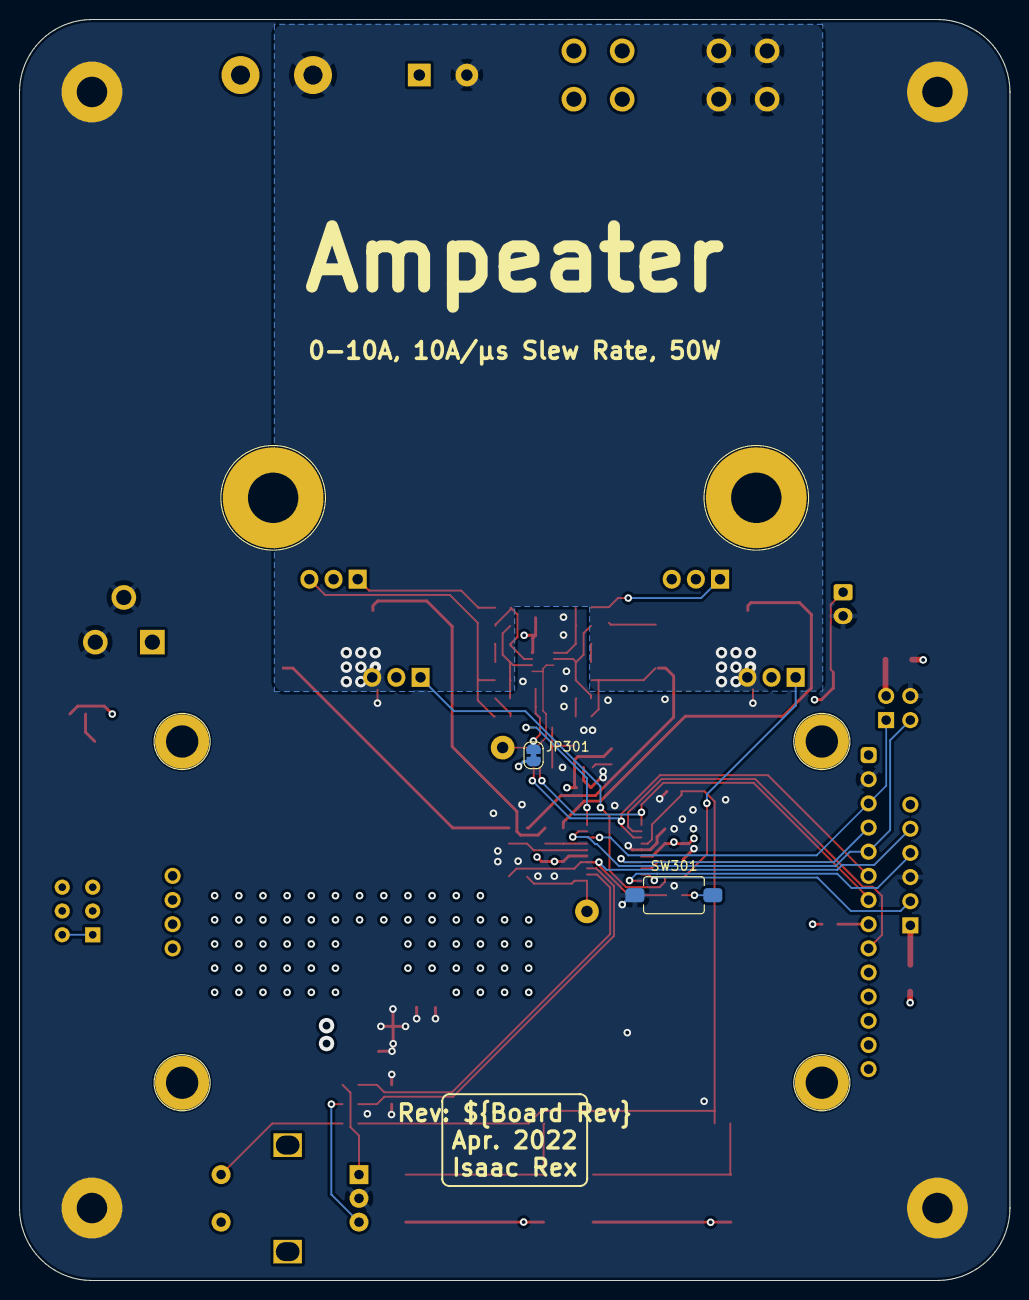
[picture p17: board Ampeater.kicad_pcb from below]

Board: 4 copper layers, 104.1 x 132.6 mm, 97 parts (2 on the bottom side), 59 nets.

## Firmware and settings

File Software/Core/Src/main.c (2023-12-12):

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
/* Includes ------------------------------------------------------------------*/
#include "main.h"
#include "adc.h"
#include "dma.h"
#include "spi.h"
#include "usart.h"
#include "gpio.h"

/* USER CODE BEGIN Includes */
#include "5x5_font.h"
#include "ILI9341_GFX.h"
#include "ILI9341_STM32_Driver.h"
#include "buttons.h"
#include "encoder.h"
#include "dac.h"
#include <stdio.h>
#include <string.h>


/* USER CODE END Includes */

/* USER CODE BEGIN PTD */
#define RS_HIGH_RANGE_OHMS  0.0909
#define RS_LOW_RANGE_OHMS   1.000
#define ISET_MAX_HIGH_AMPS  10.00
#define RES_HIGH_RANGE_AMPS 0.01 // Current set/read resolution in HIGH range
#define RES_LOW_RANGE_AMPS  0.001 // Current set/read resolution in LOW range
#define ISET_MAX_LOW_AMPS   1.000
#define ENCODER_MAX_VAL_HIGH ((uint32_t) (ENCODER_TICKS_PER_DETENT * \
                                         (ISET_MAX_HIGH_AMPS / RES_HIGH_RANGE_AMPS)))
#define ENCODER_MAX_VAL_LOW  ((uint32_t) (ENCODER_TICKS_PER_DETENT * \
                                         (ISET_MAX_LOW_AMPS / RES_LOW_RANGE_AMPS)))
#define ENCODER_MIN_VAL 0


#define NUM_DISPLAYED_DIGITS 4 // Max number of digits to display for readout
#define FORMATTER_HIGH_RNG "%d.%02d " // Extra space to remove trailing 0's in HIGH range
#define FORMATTER_LOW_RNG  "%d.%03d"
#define VALUE_CHAR_SCALER 4
#define INFO_CHAR_SCALER 3
// Y distance between new lines (in pixels)
#define VALUE_LCD_Y_OFFSET (CHAR_HEIGHT * VALUE_CHAR_SCALER + 5)
#define INFO_LCD_Y_OFFSET (CHAR_HEIGHT * INFO_CHAR_SCALER + 5)
// Start position for data labels
#define IMEAS_TXT_LCD_X_START 10 
#define IMEAS_TXT_LCD_Y_START 5 
#define ISET_TXT_LCD_X_START  10 
#define ISET_TXT_LCD_Y_START  (IMEAS_TXT_LCD_Y_START + \
                                VALUE_LCD_Y_OFFSET + INFO_LCD_Y_OFFSET)
// Start position for imeasured display data
#define IMEASURED_LCD_X_START (IMEAS_TXT_LCD_X_START)
#define IMEASURED_LCD_Y_START (IMEAS_TXT_LCD_Y_START + INFO_LCD_Y_OFFSET - 5)
// Start position for iset display data
#define ISET_LCD_X_START (ISET_TXT_LCD_X_START)
#define ISET_LCD_Y_START (ISET_TXT_LCD_Y_START + INFO_LCD_Y_OFFSET - 5)
#define OUTPUT_LCD_X_START 5
#define OUTPUT_LCD_Y_START 160
#define OUTPUT_ON_COLOR   GREEN
#define OUTPUT_OFF_COLOR  0x80E1
#define RANGE_LCD_X_START 165
#define RANGE_LCD_Y_START OUTPUT_LCD_Y_START
#define RANGE_HIGH_COLOR  ORANGE
#define RANGE_LOW_COLOR   CYAN
/* USER CODE END PTD */

/* USER CODE BEGIN PD */
#define USE_LCD
/* USER CODE END PD */


/* USER CODE BEGIN PV */
typedef enum {
    LOW_RANGE = 0,
    HIGH_RANGE = 1
} RangeMode_t;
/* USER CODE END PV */

void SystemClock_Config(void);
/* USER CODE BEGIN PFP */
void displayInfo(uint32_t output_on, uint32_t range_mode, 
                    float iset, float imeasured);
void setRange(RangeMode_t range_mode);
/* USER CODE END PFP */

/**
  * @brief  The application entry point.
  * @retval int
  */
int main(void)
{
  /* USER CODE BEGIN 1 */
    ButtonStates_TypeDef *buttons;
    ADC_HandleTypeDef *   adc;
  /* USER CODE END 1 */

  /* MCU Configuration--------------------------------------------------------*/

  /* Reset of all peripherals, Initializes the Flash interface and the Systick. */
  HAL_Init();

  /* Configure the system clock */
  SystemClock_Config();

  /* Initialize all configured peripherals */
  MX_GPIO_Init();
  MX_DMA_Init();
  MX_ADC_Init();
  MX_SPI1_Init();
  MX_USART2_UART_Init();
  /* USER CODE BEGIN 2 */
  ENCODER_init(ENCODER_MIN_VAL, ENCODER_MAX_VAL_LOW);
  DAC_init();
  buttons = BUTTONS_init();
  adc = HAL_ADC_getInstance();
  HAL_ADCEx_Calibration_Start(adc, ADC_SINGLE_ENDED);
  char out_buff[100] = {0};
  uint32_t output_on = 0;
  uint16_t vsense_raw = 0; // ADC reading from Vsense node
  uint16_t vfet_raw = 0; // ADC reading from VFET node
  RangeMode_t range_mode = LOW_RANGE;
  float vref = 3.3; // V TODO: Calculate using Vrefint
  float vRs = 0.0; // Voltage across sense resistor
  float imeasured = 0.0; // Measured sink current
  float iset = 0.0; // Set current
  float vset = 0.0; // DAC set voltage

  // Initialize the current range to LOW
  setRange(LOW_RANGE);

#ifdef USE_LCD
    HAL_UART_MspDeInit(UART_getInstance(UART2));
    ILI9341_Init(); // initial driver setup to drive ili9341
    ILI9341_Set_Rotation(SCREEN_HORIZONTAL_2);
    ILI9341_Fill_Screen(BLACK);
    ILI9341_Draw_Text("Measured", 
                        IMEAS_TXT_LCD_X_START, IMEAS_TXT_LCD_Y_START,
                        WHITE, INFO_CHAR_SCALER, BLACK);
    ILI9341_Draw_Text("Set", 
                        ISET_TXT_LCD_X_START, ISET_TXT_LCD_Y_START,
                        WHITE, INFO_CHAR_SCALER, BLACK);
    ILI9341_Draw_Text("Output", 
                        OUTPUT_LCD_X_START, OUTPUT_LCD_Y_START,
                        WHITE, INFO_CHAR_SCALER, BLACK);
    ILI9341_Draw_Text("Range", 
                        RANGE_LCD_X_START, RANGE_LCD_Y_START,
                        WHITE, INFO_CHAR_SCALER, BLACK);
#endif

  /* USER CODE END 2 */

  /* Infinite loop */
  /* USER CODE BEGIN WHILE */
    while (1) {
        /***************************\
         *  Process button presses *
        \***************************/
        BUTTONS_update();

        // ---------- Range Selection ---------- 
        if (buttons->rangePressed) {
            if (range_mode == HIGH_RANGE) {
                // Set to LOW mode
                range_mode = LOW_RANGE;
                setRange(LOW_RANGE);
            } else {
                // Set to HIGH mode
                range_mode = HIGH_RANGE;
                setRange(HIGH_RANGE);
            }
        }

        // ---------- Output Toggle ---------- 
        if (buttons->togglePressed) output_on = !output_on;

        // ---------- Set Slew Rate ---------- 
        // TODO: Implement slew rate limiting

        /**************************\
         *    Update Iset value   *
        \**************************/
        if (range_mode == LOW_RANGE) {
            iset = ((float) ENCODER_getValue() / ENCODER_MAX_VAL_LOW) * ISET_MAX_LOW_AMPS;
            vset = iset * RS_LOW_RANGE_OHMS;
        } else {
            iset = ((float) ENCODER_getValue() / ENCODER_MAX_VAL_HIGH) * ISET_MAX_HIGH_AMPS;
            vset = iset * RS_HIGH_RANGE_OHMS;
        } 
        DAC_setVolts((output_on ? vset : 0.000));

        /**************************\
         *  Calcluate Isink value *
        \**************************/
        vsense_raw = ADC_readChannel(ADC_VSENSE_CHANNEL_IDX);
        vfet_raw = ADC_readChannel(ADC_VFET_CHANNEL_IDX);
        vRs = vref * (vsense_raw - vfet_raw) / ADC_MAX_READING;
        imeasured = vRs / 
            (range_mode == LOW_RANGE ? RS_LOW_RANGE_OHMS : RS_HIGH_RANGE_OHMS);
        
        /**************************\
         *     Update  display    *
        \**************************/
        displayInfo(output_on, range_mode, iset, imeasured);

    /* USER CODE END WHILE */

    /* USER CODE BEGIN 3 */
    }
  /* USER CODE END 3 */
}

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
/* USER CODE BEGIN 4 */

/**
 * @brief Updates the user on the system states. iset and imeasured will always
 * display 4 digits. If range_mode is LOW, the output format will be x.xxx. If
 * range_mode is HIGH, the output will be xx.xx
 * 
 * @param output_on output state
 * @param range_mode output range
 * @param iset set output current
 * @param imeasured measured output current
 */
void displayInfo(uint32_t output_on, uint32_t range_mode, 
                    float iset, float imeasured) 
{
    static uint32_t output_on_last = 1;
    static uint32_t range_last = HIGH_RANGE;
    // Track digits so we can only redraw what's new. len = NUM_DIGITS + '.' + '\0' 
    static char imes_strbuff_last[NUM_DISPLAYED_DIGITS + 2] = {0}; 
    static char iset_strbuff_last[NUM_DISPLAYED_DIGITS + 2] = {0}; 

    char i_strbuff[NUM_DISPLAYED_DIGITS + 2]; // NUM_DIGITS + '.' + '\0' 
    uint32_t whole_part;
    uint32_t frac_part;
    // Precision factor is used to determine how many fractional digits to use
    uint32_t precision_factor = (range_mode == HIGH_RANGE) ? 100 : 1000;

    
    // Compute and display iset and imeasured
    const char* formatter = (range_mode == HIGH_RANGE) ? 
                                    FORMATTER_HIGH_RNG : FORMATTER_LOW_RNG;
    // ---------- imeasured ---------- 
    whole_part = (uint32_t) imeasured;
    frac_part = ((uint32_t) (imeasured * precision_factor)) % precision_factor;
    sprintf(i_strbuff, formatter, whole_part, frac_part);

    uint32_t cursor_x = IMEASURED_LCD_X_START;
    uint32_t cursor_y = IMEASURED_LCD_Y_START;
    for (int i = 0; i < NUM_DISPLAYED_DIGITS + 1; i++) {
        if (i_strbuff[i] != imes_strbuff_last[i]) {
            ILI9341_Draw_Char(i_strbuff[i], cursor_x, cursor_y, WHITE, VALUE_CHAR_SCALER, BLACK);
        }
        if (i_strbuff[i] == '.') {
            cursor_x += CHAR_WIDTH * VALUE_CHAR_SCALER * 1;
        } else {
            cursor_x += CHAR_WIDTH * VALUE_CHAR_SCALER;
        }

        imes_strbuff_last[i] = i_strbuff[i];
    }

    // ---------- iset ---------- 
    whole_part = (uint32_t) iset;
    frac_part = ((uint32_t) (iset * precision_factor)) % precision_factor;
    sprintf(i_strbuff, formatter, whole_part, frac_part);

    cursor_x = ISET_LCD_X_START;
    cursor_y = ISET_LCD_Y_START;
    for (int i = 0; i < NUM_DISPLAYED_DIGITS + 1; i++) {
        if (i_strbuff[i] != iset_strbuff_last[i]) {
            ILI9341_Draw_Char(i_strbuff[i], cursor_x, cursor_y, WHITE, VALUE_CHAR_SCALER, BLACK);
        }
        if (i_strbuff[i] == '.') {
            cursor_x += CHAR_WIDTH * VALUE_CHAR_SCALER * 1;
        } else {
            cursor_x += CHAR_WIDTH * VALUE_CHAR_SCALER;
        }

        iset_strbuff_last[i] = i_strbuff[i];
    }

    // Draw output state
    if (output_on != output_on_last) {
        uint32_t color = output_on == 1 ? OUTPUT_ON_COLOR : OUTPUT_OFF_COLOR;
        ILI9341_Draw_Text(output_on == 1 ? "ON " : "OFF", 
                            OUTPUT_LCD_X_START, OUTPUT_LCD_Y_START + INFO_LCD_Y_OFFSET,
                            color, VALUE_CHAR_SCALER, BLACK);
        output_on_last = output_on;
    }

    // Draw range state
    if (range_mode != range_last) {
        uint32_t color = range_mode == HIGH_RANGE ? 
                                        RANGE_HIGH_COLOR : RANGE_LOW_COLOR;
        ILI9341_Draw_Text(range_mode == HIGH_RANGE ? "High" : "Low ", 
                            RANGE_LCD_X_START, RANGE_LCD_Y_START + INFO_LCD_Y_OFFSET,
                            color, VALUE_CHAR_SCALER, BLACK);
        range_last = range_mode;
    }
}

void setRange(RangeMode_t range_mode) {
    if (range_mode == HIGH_RANGE) {
        // Set to LOW mode
        HAL_GPIO_WritePin(RANGE_SW_GPIO_Port, RANGE_SW_Pin, LOW_RANGE);
        // Scale the encoder value so that the output current stays the 
        // same (or clamps)
        ENCODER_setValue(ENCODER_getValue() * 
                            ISET_MAX_LOW_AMPS / ISET_MAX_HIGH_AMPS);
    } else {
        // Set to HIGH mode
        HAL_GPIO_WritePin(RANGE_SW_GPIO_Port, RANGE_SW_Pin, HIGH_RANGE);
        // Scale the encoder value so that the output current stays the 
        // same (or clamps)
        ENCODER_setValue(ENCODER_getValue() * 
                            ISET_MAX_HIGH_AMPS / ISET_MAX_LOW_AMPS);

    }
}
/* USER CODE END 4 */
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


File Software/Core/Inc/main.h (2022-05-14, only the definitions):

#define ENCODER_A_Pin GPIO_PIN_14
#define ENCODER_A_GPIO_Port GPIOC
#define ENCODER_A_EXTI_IRQn EXTI4_15_IRQn
#define ENCODER_B_Pin GPIO_PIN_15
#define ENCODER_B_GPIO_Port GPIOC
#define ENCODER_B_EXTI_IRQn EXTI4_15_IRQn
#define Vsense_R_Pin GPIO_PIN_0
#define Vsense_R_GPIO_Port GPIOA
#define Vsense_FET_Pin GPIO_PIN_1
#define Vsense_FET_GPIO_Port GPIOA
#define UART_TX_SPI_CS_LCD_Pin GPIO_PIN_2
#define UART_TX_SPI_CS_LCD_GPIO_Port GPIOA
#define UART_RX_SPI_DC_LCD_Pin GPIO_PIN_3
#define UART_RX_SPI_DC_LCD_GPIO_Port GPIOA
#define SPI_CS_DAC_Pin GPIO_PIN_4
#define SPI_CS_DAC_GPIO_Port GPIOA
#define SPI_SCK_Pin GPIO_PIN_5
#define SPI_SCK_GPIO_Port GPIOA
#define SPI_MISO_Pin GPIO_PIN_6
#define SPI_MISO_GPIO_Port GPIOA
#define SPI_MOSI_Pin GPIO_PIN_7
#define SPI_MOSI_GPIO_Port GPIOA
#define Vbtns_Pin GPIO_PIN_1
#define Vbtns_GPIO_Port GPIOB
#define SPI_nRST_LCD_Pin GPIO_PIN_9
#define SPI_nRST_LCD_GPIO_Port GPIOA
#define RANGE_SW_Pin GPIO_PIN_10
#define RANGE_SW_GPIO_Port GPIOA
#define ADC_VSENSE_CHANNEL_IDX 0
#define ADC_VFET_CHANNEL_IDX   1
#define ADC_BTN_CHANNEL_IDX    2

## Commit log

2022-03-28 Adding files after making repo
    [Ampeater Sim.kicad_pcb, Ampeater Sim.kicad_sch, Ampeater.kicad_pcb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]
2022-04-10 Finished board layout
    [Ampeater-B_Cu.gbr, Ampeater-B_Mask.gbr, Ampeater-B_Paste.gbr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]
2022-04-23 Added fan shroud 3D model and heatsink drawing
    [2x3inch Serated Heat Sink.step, CC_Load_Controller.kicad_sch, Fan Shroud.step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]
2022-05-14 Updated fan shroud files
    [Fan Shroud.3mf, Fan Shroud.step]
2022-05-14 Added initial prototype software
    [Ampeater.kicad_sch, CC_Load_Controller.kicad_sch]
2022-05-15 Updated simulation files
    [Ampeater Sim.kicad_pcb, Ampeater Sim.kicad_sch]
2023-12-12 Fixed LOW/HIGH range issue on boot
    Fixed an issue that caused Ampeater to display LOW range but actually be
    in HIGH range on boot.
    [main.c]

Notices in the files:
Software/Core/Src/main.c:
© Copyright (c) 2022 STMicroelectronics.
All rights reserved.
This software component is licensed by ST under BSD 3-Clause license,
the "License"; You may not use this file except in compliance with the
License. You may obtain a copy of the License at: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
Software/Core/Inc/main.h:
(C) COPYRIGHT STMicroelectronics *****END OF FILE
